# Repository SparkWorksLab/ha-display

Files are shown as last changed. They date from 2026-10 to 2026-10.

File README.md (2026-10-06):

<div align="center">

# Home Assistant Display






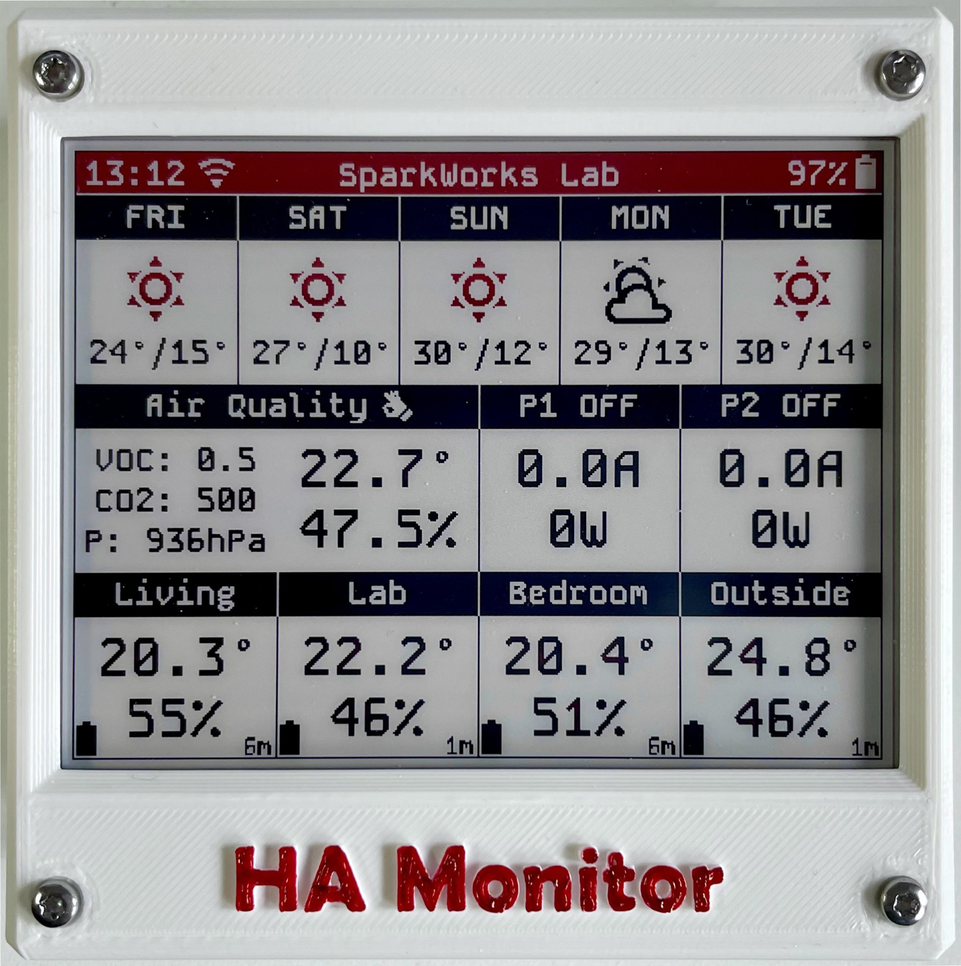
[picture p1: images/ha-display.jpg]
HA Display


**A low-power ESPHome e-paper dashboard for Home Assistant.**

A battery-powered Home Assistant display built around an ESP32-S3 and a 4.2" three-color e-paper display.

The device periodically wakes up, connects to Home Assistant, retrieves sensor data, updates the display, and then returns to deep sleep to minimize power consumption.

</div>

---

## Contents

- [Overview](#overview)
- [Features](#features)
- [System Architecture](#system-architecture)
- [Project Structure](#project-structure)
- [Display](#display)
- [Power Management](#power-management)
- [Home Assistant Integration](#home-assistant-integration)
- [Hardware](#hardware)
- [Firmware](#firmware)
- [Enclosure](#enclosure)
- [Installation](#installation)
- [Future Improvements](#future-improvements)
- [Design Principles](#design-principles)
- [References](#references)
- [License](#license)

---

## Overview

The **Home Assistant Display** is a battery-powered e-paper dashboard
designed to provide a quick overview of home information without requiring
a permanently powered screen.

The display combines data from Home Assistant with measurements from local
sensors and presents the information through a modular set of e-paper
widgets.

The low-power architecture allows the device to remain in deep sleep for
most of the time, waking periodically to update the display.

The project is designed to be modular and expandable, with separate
documentation for the firmware, hardware, and enclosure.

---

## Features

* 4.2" three-color e-paper display.
* Home Assistant integration through the ESPHome API.
* Weather forecast display.
* Local temperature, humidity, and atmospheric pressure monitoring.
* BME688 gas resistance and air quality monitoring.
* Smart Plug status monitoring.
* Current and power consumption display.
* Room temperature and humidity monitoring.
* Sensor availability detection.
* Low-power operation using deep sleep.
  * Automatic configurable interval refresh cycle during the day.
  * Extended deep sleep during the night.
* Manual wake-up button.  
* Li-Ion battery voltage monitoring.
* Wi-Fi connection status indication.
* Home Assistant API connection status indication.
* Configurable RGB debug LED.
* Modular display and widget architecture.
* Doxygen documentation.
* *Fail-Safe Operation:* Network mitigation routines preventing infinite loops and battery drain during Wi-Fi or HA outages.

---

## System Architecture

```mermaid
flowchart LR

    HA[Home Assistant]

    subgraph Display["HA Display"]
        ESP[ESP32-S3]
        DISPLAY[4.2-inch E-paper Display]
        BME[BME688]
        BAT[Li-Ion Battery]
        BUTTON[Wake-up Button]
    end

    SENSORS[Room Sensors]
    PLUGS[Smart Plugs]
    WEATHER[Weather Integration]

    SENSORS --> HA
    PLUGS --> HA
    WEATHER --> HA

    HA <-->|ESPHome API / Wi-Fi| ESP

    BME -->|I2C| ESP
    BAT -->|GPIO1| ESP
    BUTTON -->|GPIO4| ESP
    ESP --> DISPLAY
```

The display acts as a low-power endpoint for Home Assistant.

Home Assistant provides aggregated data and configuration, while the ESP32
is responsible for local sensor measurements, display rendering,
connectivity, and power management.

---

## Project Structure

```text
.
├── enclosure/       # 3D-printable enclosure and mechanical documentation
├── firmware/        # ESPHome configuration and C++ firmware
├── hardware/        # Schematics, PCB layouts, and BOMs
├── images/          # Project images and documentation assets
├── README.md        # Main project documentation
└── LICENSE          # AGPL-3.0 License
```

Each major part of the project has its own documentation:

* [Firmware](firmware/) — ESPHome configuration, C++ code,
sensors, display widgets, power management, and Home Assistant
integration.
* [Hardware](hardware/) — electronics, schematics, PCB
revisions, and BOM.
* [Enclosure](enclosure/) — 3D-printable enclosure files,
assembly information, and mechanical details.

---

## Display

The display is divided into several independent widgets.

* **Header**

  * Last update time.
  * Wi-Fi and Home Assistant connection status.
  * Title.
  * Battery status.

* **Top Section**

  * Weather forecast.

* **Middle Section**

  * BME688 environmental and air quality data.
  * Smart Plug monitoring.

* **Bottom Section**

  * Room temperature and humidity sensors.

The display drawing code is organized into reusable functions. This makes it easy to modify the layout or add new widgets without turning the main ESPHome display lambda into a large block of code.

### Display Layout

The 400 × 300 px screen is divided into four sections, each mapped to positions and sizes defined in `layout.h`.

<div align="center">
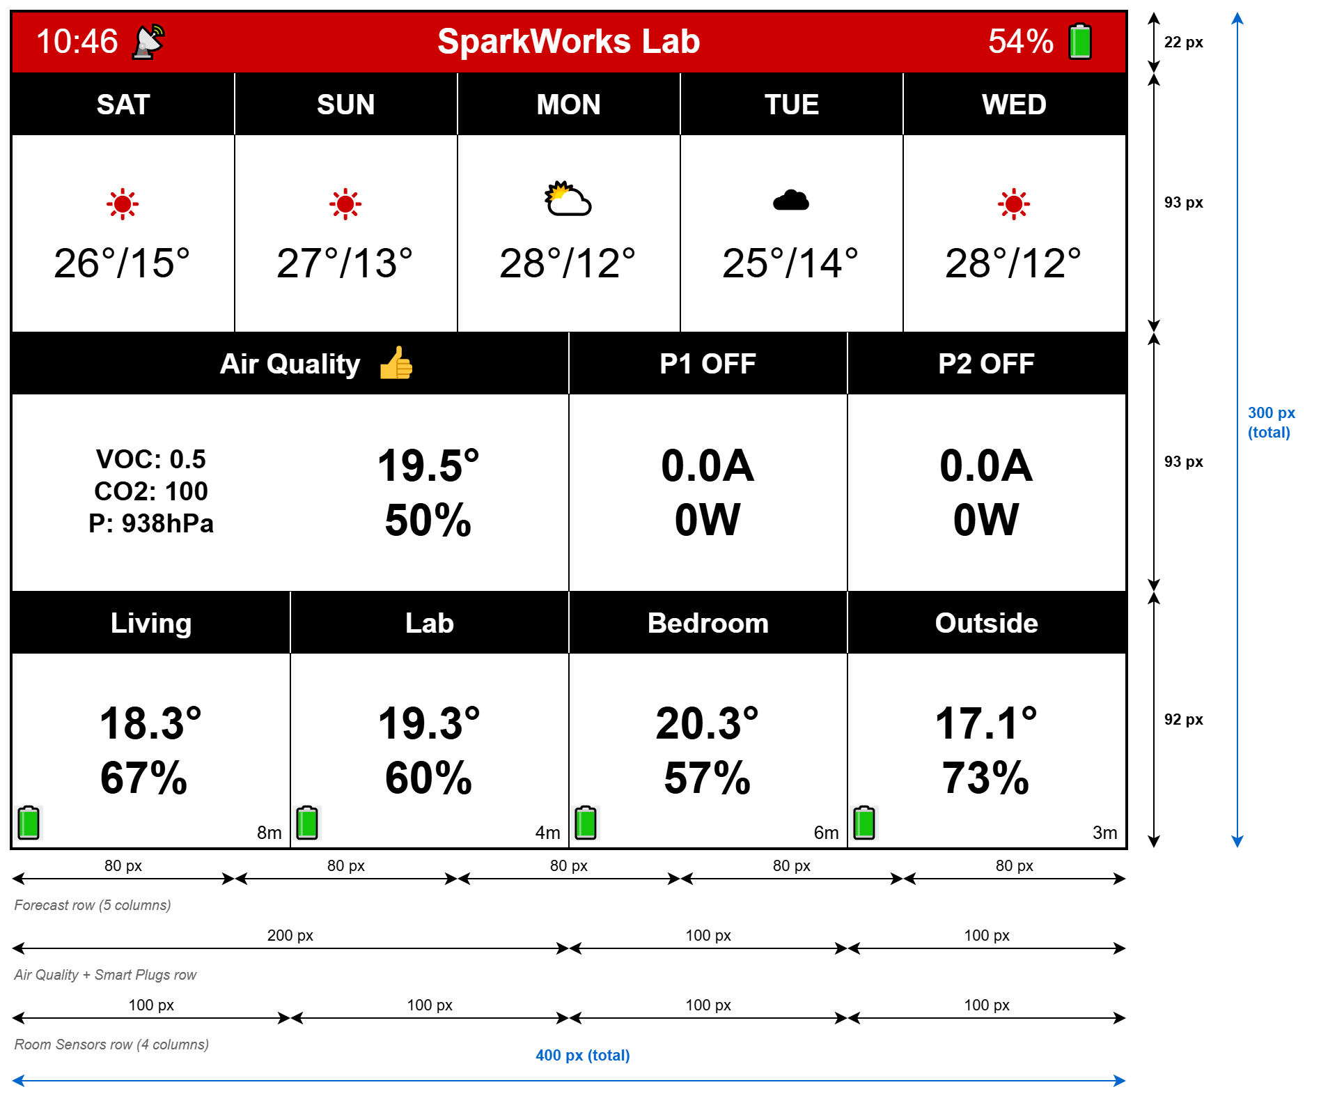
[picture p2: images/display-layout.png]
Display Layout

</div>

---

## Power Management

Low power consumption is one of the main goals of the project.

The device does not remain continuously connected to Wi-Fi. Instead, the ESP32 follows this cycle:

```mermaid
flowchart TD

    A[Wake up] --> B[Connect to Wi-Fi]

    B --> C[Connect to Home Assistant]

    C --> D[Receive Home Assistant data]

    D --> E[Read local sensors]

    E --> F[Update e-paper display]

    F --> G[Wait for display refresh]

    G --> L{Deep sleep enabled?}

    L -->|On| H{Night period?}

    H -->|No| I[Deep sleep for configured interval]

    H -->|Yes| J[Calculate time until wake time]

    J --> K[Extended deep sleep]

    I --> A
    K --> A

    L -->|Off| M[Wait configured interval]
    M --> D

    BUTTON[Manual wake-up button] -. GPIO4 .-> A
```

During the day, the display wakes up and refreshes at the interval configured through Home Assistant.

During the night, it enters a longer deep sleep period and automatically wakes up at the configured morning wake time.

The sleep schedule and daytime sleep duration can be configured directly
from Home Assistant without recompiling or reflashing the firmware.

A physical wake-up button can also be used to wake the device manually.

For detailed implementation information, see
[Power Management](firmware/README.md#power-management) in the firmware
documentation.

---

## Home Assistant Integration

The display communicates with Home Assistant through the ESPHome API.

Home Assistant provides:

* Room sensor data.
* Smart Plug information.
* Weather forecast data.
* Sleep schedule configuration.
* Daytime sleep duration.
* Deep-sleep enable/disable state.

Several Home Assistant helpers are used as persistent configuration
parameters for the display.

The current configuration includes:

* Sleep start hour.
* Wake-up hour.
* Daytime sleep duration.
* Deep-sleep enable/disable.

Because these values are stored by Home Assistant, they remain available while the ESP32 is in deep sleep.

When the display wakes and reconnects to Home Assistant, it retrieves the current configuration and uses it to determine its next operating cycle.

Changes made in Home Assistant therefore take effect on the next wake-up cycle.

The physical wake-up button can be used to apply configuration changes immediately instead of waiting for the next scheduled wake-up.

Detailed Home Assistant configuration is documented in the
[firmware](firmware/README.md#home-assistant-integration) documentation.

---

## Hardware

The HA Display has been developed through two hardware versions:

### Prototype

The prototype is built using an **ESP32-S3-DevKitC-1 development board** and a
2.54mm pitch protoboard. It was used to develop and validate the hardware and
software before designing the dedicated PCB.

Main hardware components:

* ESP32-S3-DevKitC-1 development board.
* WeAct Studio 4.2" (400 × 300 px) three-color e-paper display.
* Bosch BME688 environmental and air quality sensor.
* Li-Ion 18650 battery.
* 1S BMS/protection module.
* TPS63802 buck-boost 3,3v converter module.
* TP4056 USB-C Li-Ion charger module.
* 1 x push button for manual wake-up.

[View prototype hardware documentation](hardware/prototype/README.md)

### v1.0 Dedicated PCB

<div align="center">
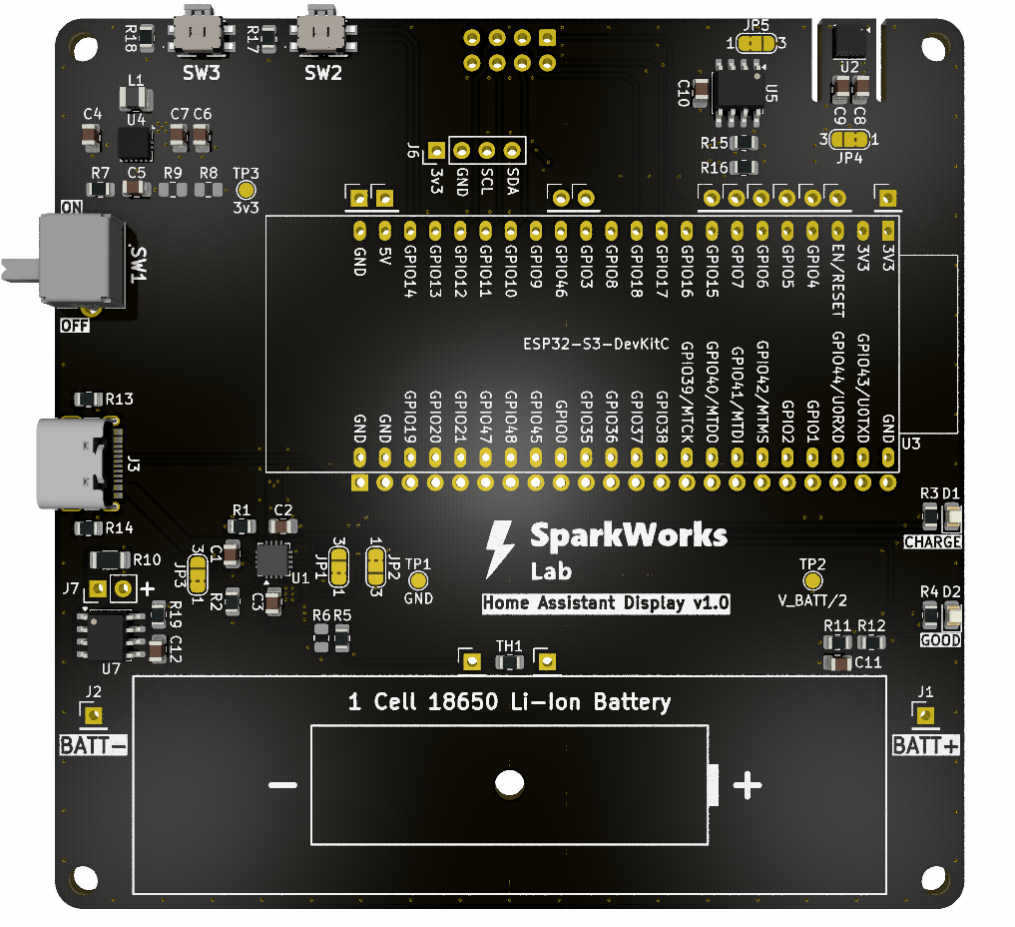
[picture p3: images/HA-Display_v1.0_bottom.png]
Wiring

</div>

The v1.0 hardware replaces the prototype wiring with a **dedicated 4-layer PCB** designed specifically for the HA Display with controlled USB differential pair impedances and optimized power and ground planes.
* ESP32-S3-DevKitC-1 development board.
* WeAct Studio 4.2" (400 × 300 px) three-color e-paper display.
* Bosch BME680/BME688 environmental sensor.
* Li-Ion 18650 battery.
* BQ24072: Li-Ion battery charger and power-path management IC (prioritizes USB input, bypassing cell micro-cycling).
* TPS63001: High-efficiency buck-boost converter ensuring a stable 3.3V rail down to battery cutoff.
* XB8089D: Integrated SOP8 advanced battery protection sub-circuit.
* Redundant DPDT Switch: Dual parallel-trace slide switch ensuring high mechanical robustness and reduced contact resistance.
* EEPROM: Onboard I2C storage for non-volatile data storage.
* 2 x push buttons for navigation and manual wake-up.
* Test points for debugging and measurements.
* Expansion headers for additional peripherals.
* Jumper at GND to measure current consumption easily.

[View v1.0 hardware documentation](hardware/v1.0/README.md)

### Home Assistant Server

Both versions communicate with a **Home Assistant server running on a
Raspberry Pi 3 B+** through ESPHome.

---

## Firmware

The firmware is based on ESPHome with an additional modular C++ layer for display widgets, battery estimation, power management, layout, and other reusable functionality.

The firmware configuration is divided into small YAML packages, while application-specific functionality is implemented through C++ header files.

This separation makes the firmware easier to maintain and allows hardware configuration, Home Assistant entities, display layout, and application logic to evolve independently.

Go to [firmware](firmware/README.md) documentation.

---

## Enclosure

The project includes a dedicated 3D-printed enclosure designed around the
display and electronics.

The enclosure documentation contains:

* STL files.
* Assembly information.
* Mechanical details.
* Printing recommendations.

Go to [enclosure](enclosure/README.md) documentation.

---

## Installation

The complete installation procedure is documented in the
[firmware](firmware/README.md#installation) documentation.

The general process is:

1. Install Python and ESPHome.
2. Clone this repository.
3. Configure the Home Assistant entities.
4. Configure Wi-Fi credentials.
5. Install the required Home Assistant package.
6. Configure the Home Assistant helpers.
7. Compile the ESPHome firmware.
8. Upload the firmware to the ESP32.

---

## Future Improvements

Some ideas for future development include:

* Particulate matter monitoring.
* Dedicated CO₂ measurement.
* Additional air quality sensors.
* Improved BME688 gas analysis and classification.
* ADC calibration based on measured voltage.
* Battery discharge testing and a custom State of Charge curve.
* Improved State of Charge estimation.
* Dynamic e-paper refresh timing.
* Historical sensor trends.
* Additional Home Assistant entities.
* Configurable display layouts.

---

## Design Principles

The goal of this project is to create a simple, low-power, and fully customizable Home Assistant information display.

The project focuses on:

* Low power consumption.
* Modular code.
* Reusable display widgets.
* Easy integration with Home Assistant.
* Battery operation.
* Simple and accessible hardware.
* Easy future expansion.

The architecture intentionally separates Home Assistant data aggregation from the ESP32 application logic.

Home Assistant provides the information and configuration, while the ESP32 focuses on local sensing, display rendering, connectivity, and power management.

---

## References

* [Home Ambient (Faulty Project).](https://faultyproject.es/category/proyectos/home-ambient/)
* [ESPHome E-ink Weather board.](https://github.com/xangin/eink-weather-board)
* [Material Design Icons Library.](https://pictogrammers.com/library/mdi/)

---

## License

The source code in this repository is licensed under the GNU Affero General Public License v3.0 (AGPL-3.0).

See the [LICENSE](LICENSE) file for the full license text.

Third-party assets included in this repository may be distributed under their respective licenses.

### Third-Party Assets

This project includes the Material Design Icons webfont by Pictogrammers.

The font is distributed under the Apache License 2.0.

See the [Pictogrammers](https://pictogrammers.com/) website and the [Apache License 2.0](https://www.apache.org/licenses/LICENSE-2.0) for more information.

### Images and Photographs

Unless otherwise stated, photographs and images in this repository are copyright © 2026 SparkWorksLab.

They are provided for documentation and demonstration purposes only and are not covered by the AGPL-3.0 License.

Permission is required for their reuse, redistribution, or commercial use.

---

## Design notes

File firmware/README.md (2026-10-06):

<div align="center">

# HA Display: Firmware

ESPHome firmware, configuration, and C++ application logic
for the Home Assistant Display

</div>

---

## Contents

- [Overview](#overview)
- [Project Structure](#project-structure)
- [Firmware Architecture](#firmware-architecture)
- [ESPHome Configuration](#esphome-configuration)
- [C++ Application Layer](#c-application-layer)
- [Display System](#display-system)
- [Home Assistant Integration](#home-assistant-integration)
- [Monitoring and Sensors](#monitoring-and-sensors)
- [Power Management](#power-management)
- [Deep Sleep Configuration](#deep-sleep-configuration)
- [Manual Wake-Up](#manual-wake-up)
- [Connectivity and Fail-Safe Operation](#connectivity-and-fail-safe-operation)
- [Debug RGB LED](#debug-rgb-led)
- [BSEC2 Experimental Configuration](#bsec2-experimental-configuration)
- [Installation](#installation)
- [Configuration](#configuration)
- [Troubleshooting](#troubleshooting)
- [Doxygen Documentation](#doxygen-documentation)

---

## Overview

The firmware is based on **ESPHome** and uses a modular C++ application layer for functionality that is more convenient to implement outside the ESPHome YAML configuration.

ESPHome provides:

* Hardware configuration.
* Wi-Fi connectivity.
* Home Assistant API communication.
* Sensor integration.
* Deep-sleep control.
* GPIO handling.
* OTA and serial firmware updates.

The C++ layer provides:

* Display rendering.
* Reusable display widgets.
* Display layout definitions.
* Battery State of Charge estimation.
* Power-management calculations.
* Weather icon conversion.
* RGB debug LED helpers.

The firmware is intentionally divided into small reusable components so that individual parts can be modified without turning the main ESPHome configuration into a large monolithic file.

---

## Project Structure

The project is divided into small, reusable YAML configuration files and C++ header files.

```text
.
├── fonts/
│   └── materialdesigniconswebfont.ttf
│
├── include/
│   ├── battery.h
│   ├── display.h
│   ├── display_bsec.h
│   ├── layout.h
│   ├── led.h
│   ├── power.h
│   └── weather_icons.h
│
├── packages/
│   ├── display.yaml
│   ├── entities.yaml
│   ├── fonts.yaml
│   ├── forecast.yaml
│   ├── sensors.yaml
│   ├── sensors_bsec.yaml
│   └── wifi.yaml
│
├── .gitignore
├── HA-Display.yaml
├── ha_display_sensor.yaml
├── README.md
└── secrets.example.yaml
```
---

## Firmware Architecture

The main ESPHome configuration includes the individual YAML packages and the C++ header files.

The standard firmware uses `sensors.yaml` and `display.h`.

An alternative BSEC2 configuration is provided in `sensors_bsec.yaml` and `display_bsec.h` for experimental or continuously powered applications.

Only one sensor/display profile is intended to be active at a time.

The default profile uses `sensors.yaml` and `display.h`, while the optional BSEC2 profile uses `sensors_bsec.yaml` and `display_bsec.h`.

---

## ESPHome Configuration

The firmware configuration is split into several ESPHome packages, each responsible for a specific subsystem.

### `HA-Display.yaml`

This is the main ESPHome configuration file.

It defines the ESP32-S3 hardware, includes the project packages, references the external C++ headers, and provides the top-level configuration required to build the firmware.

The main configuration should remain relatively small because most functionality is delegated to the individual packages and C++ modules.

### `display.yaml`

Configures the e-paper display and the main display update lambda.

The display layout is implemented through reusable drawing functions defined in the project header files.

### `entities.yaml`

Defines the Home Assistant entities imported into ESPHome, including room sensors, Smart Plug data, battery information, and configurable sleep schedule parameters.

### `fonts.yaml`

Defines the fonts and Material Design icon glyphs used by the e-paper display.

### `forecast.yaml`

Defines the Home Assistant entities used to retrieve weather forecast data and makes the forecast attributes available to the display.

### `sensors.yaml`

Same configuration as `sensors.yaml` adding BSEC2 algorithm for the BME68x sensor.

### `sensors_bsec.yaml`

Configures locally connected sensors and Home Assistant entities used by the display.

Includes environmental measurements, battery monitoring, and configurable  sleep schedule entities.

### `wifi.yaml`

Configures the Wi-Fi connection and ESPHome API used to communicate with Home Assistant.

### `secrets.example.yaml`

Copy this file to `secrets.yaml` and update it with your own Wi-Fi credentials:

```yaml
wifi_ssid: "YOUR_WIFI_SSID"
wifi_password: "YOUR_WIFI_PASSWORD"
```

The `secrets.yaml` file should not be committed to the repository.

---

## C++ Application Layer

Application-specific functionality is implemented through C++ header files.

### `battery.h`

Contains battery-related helper functions.

The battery State of Charge is estimated using a voltage lookup table instead of a simple linear calculation.

This provides a more realistic approximation of the charge level of a Li-Ion cell.

### `display.h`

Provides reusable functions for drawing the different widgets displayed on the e-paper dashboard.

 The widgets include the header, weather forecast, environmental sensor, Smart Plug display, room sensors, and battery indicators. For example:

* `drawHeader()`.
* `drawBatteryIcon()`.
* `drawForecast()`.
* `drawAirSensor()`.
* `drawSmartPlugs()`.
* `drawRoomSensors()`.

### `display_bsec.h`

Same as `display.h` replacing `drawAirSensor()` to show BSEC2 calculated data.

### `layout.h`

Contains display layout definitions such as:

* Screen dimensions.
* Widget positions.
* Margins.
* Alignment constants.
* Widget spacing.

Keeping the layout separate from the drawing functions makes it easier to reorganize the display without modifying the widget implementation.

### `led.h`

Contains helper functions for the RGB status LED.

The LED can be enabled for debugging purposes using a compile-time definition:

```cpp
#define DEBUG_LED
```

When debugging is disabled, the LED control code is excluded from the build.

### `power.h`

Contains power management helper functions.

The current implementation calculates the deep sleep duration dynamically based on the current time and configurable sleep start and wake times.

This allows the display to:

* Refresh every 15 minutes during the day.
* Enter a single extended deep sleep period during the night.
* Wake up automatically at the configured morning wake time.

### `weather_icons.h`

Provides helper functions and definitions for converting Home Assistant weather condition strings into the corresponding Material Design icons used by the e-paper display.

### `.gitignore`

The repository includes a `.gitignore` file to prevent personal configuration files, such as `secrets.yaml`, from being committed.

---

## Home Assistant Integration

The display communicates with Home Assistant through the ESPHome API.

Several Home Assistant entities are imported directly into ESPHome, including room temperature and humidity sensors, smart plug states and power consumption data, weather forecast information, and the sleep schedule configuration.

### Home Assistant Helpers

The sleep schedule is configured using three Home Assistant `input_number` helpers:

* `input_number.sleep_start_hour`
* `input_number.wake_hour`
* `input_number.sleep_duration`

Create these helpers from:

**Settings → Devices & services → Helpers → Create Helper → Number**

Configure them with:

<div align="center">

| Helper | Minimum | Maximum | Step |
| --- | --- | --- | --- |
| `input_number.sleep_start_hour` | 0 | 23 | 1 |
| `input_number.wake_hour` | 0 | 23 | 1 |
| `input_number.sleep_duration` | 5 | 60 | 5 |

</div>

These helpers act as the persistent configuration for the display. ESPHome reads their values after connecting to Home Assistant following a wake-up. See [Deep Sleep Configuration](#deep-sleep-configuration) for how they are used.

An additional helper controls whether the display uses deep sleep at all:

* `input_boolean.ha_display_deep_sleep`

Create it from:

**Settings → Devices & services → Helpers → Create Helper → Toggle**

No further configuration is needed — the display reads its state directly. See [Deep Sleep Configuration](#deep-sleep-configuration) for how it's used.

### Home Assistant Package

Some of the data displayed by the display is prepared by Home Assistant.

Before installing the ESPHome configuration, copy:

```text
ha_display_sensor.yaml
```

to the Home Assistant packages directory:

```text
/config/packages/
```

Make sure that the packages directory is included in your Home Assistant configuration.

For example:

```yaml
homeassistant:
  packages: !include_dir_named packages
```

Then restart Home Assistant.

The package creates the template entities required by the display, including weather forecast data and sensor availability states.

### Weather Forecast

Home Assistant is responsible for retrieving and preparing the weather forecast.

A template sensor stores the forecast data as attributes. The ESPHome device retrieves these attributes and displays them on the e-paper screen.

The forecast includes:

* Day.
* Weather condition.
* Maximum temperature.
* Minimum temperature.

The forecast data can be refreshed periodically to prevent outdated information from being displayed.

This is configured in the `ha_display_sensor.yaml` file.

```yaml
- trigger:
    - platform: homeassistant
      event: start

    - platform: time_pattern
      hours: "/1"
      minutes: 1

  action:
    - service: homeassistant.update_entity
      target:
        entity_id: weather.forecast_home

    - delay: "00:00:02"
    
    - service: weather.get_forecasts
      target:
        entity_id: weather.forecast_home
      data:
        type: daily
      response_variable: daily

  sensor:
    - name: "eink_sensors"
      unique_id: eink_sensors

      state: >
        {{ daily['weather.forecast_home'].forecast[0].condition }}

      attributes:

        forecast_day_1: >
          {{ as_timestamp(daily['weather.forecast_home'].forecast[0].datetime)
             | timestamp_custom('%a')
             | upper }}

        forecast_condition_1: >
          {{ daily['weather.forecast_home'].forecast[0].condition }}

        forecast_temp_max_1: >
          {{ daily['weather.forecast_home'].forecast[0].temperature | round }}

        forecast_temp_min_1: >
          {{ daily['weather.forecast_home'].forecast[0].templow | round }}
```

---

## Monitoring and Sensors

The display combines data received from Home Assistant with locally connected sensors.

### Room Temperature and Humidity Sensors

The display retrieves temperature and humidity data from Home Assistant entities. This allows the device to display environmental data collected by external sensors distributed throughout the home.

The sensor entities can be easily adapted in `entities.yaml` to match the Home Assistant configuration.

```yaml
sensor:
  - platform: homeassistant
    id: t1_temperature
    entity_id: sensor.t1_temperature

  - platform: homeassistant
    id: t1_humidity
    entity_id: sensor.t1_humidity

  - platform: homeassistant
    id: t1_battery
    entity_id: sensor.t1_battery 

  - platform: homeassistant
    id: t1_age
    entity_id: sensor.t1_sensor_age    
```

Sensor availability is also monitored to detect stale or unavailable devices. When a sensor has not reported data for an extended period, its status can be visually indicated on the display instead of presenting outdated measurements as current values.

A binary sensor is created in `entities.yaml` to handle this functionality.

```yaml
binary_sensor:
  - platform: homeassistant
    entity_id: binary_sensor.t1_sensor_state
    id: t1_online
```    

Stale or unavailable sensors can therefore be visually highlighted instead of displaying outdated values as if they were current. This is configured in the `ha_display_sensor.yaml` file. 

```yaml
- trigger:
    - platform: time_pattern
      minutes: "/1"

  binary_sensor:
    - name: T1 Sensor State
      unique_id: t1_online
      state: >
        {{ (now() - states.sensor.t1_temperature.last_updated).total_seconds() < 900 }}
```

Each Room Sensor widget displays:

* Sensor name.
* Temperature.
* Humidity.
* Battery Level.
* Minutes since last update.
* Status (Red color if not updated for more than 15 minutes).

The widget implementation is reusable:

```cpp
drawRoomSensor(
    it,
    x,
    y,
    name,
    temperature,
    humidity,
    battery,
    status,
    age);
```

A higher-level function handles the collection of Room Sensors widgets:

```cpp
drawRoomSensors(it);
```

### Smart Plug Monitoring

The display currently displays the status of two Home Assistant Smart Plugs.

The sensor entities can be easily adapted in `entities.yaml` to match the Home Assistant configuration.

```yaml
sensor:
  - platform: homeassistant
    id: p1_voltage
    entity_id: sensor.p1_voltage
  - platform: homeassistant
    id: p1_current
    entity_id: sensor.p1_current  
  - platform: homeassistant
    id: p1_power
    entity_id: sensor.p1_power

switch:
  - platform: homeassistant
    entity_id: switch.p1
    id: p1_state    
```

Each Smart Plug widget displays:

* Plug name.
* ON/OFF state.
* Current consumption.
* Power consumption.

The widget implementation is reusable:

```cpp
drawSmartPlug(
    it,
    x,
    y,
    name,
    state,
    current,
    power);
```

A higher-level function handles the collection of Smart Plug widgets:

```cpp
drawSmartPlugs(it);
```

Additional Smart Plugs can therefore be added without modifying the individual widget implementation.

### Environmental Sensor

A Bosch BME680/BME688 environmental sensor is connected directly to the ESP32 through the I2C bus.

The standard firmware uses the conventional BME68x sensor driver rather than BSEC2. This configuration provides the basic environmental measurements while remaining fully compatible with the low-power deep-sleep architecture.

The sensor is connected through I2C using address `0x77`. The address depends on the CS pin configuration of the sensor module: with CS pulled high, the sensor uses `0x77`; with CS pulled low, it uses `0x76`.

The standard configuration provides measurements such as:

* Temperature.
* Relative humidity.
* Atmospheric pressure.
* Gas resistance.
* IAQ.

The sensor values are available both:

* On the e-paper display.
* As entities in Home Assistant.

The project also includes an optional BSEC2-based configuration. See [BSEC2 Experimental Configuration](#bsec2-experimental-configuration) for details.

The environmental values are provided directly by the BME688, while the air-quality indicators are calculated by BSEC2 from the sensor measurements.

The temperature, humidity and pressure values use small change filters to avoid unnecessary updates when the measured value changes only slightly.

The IAQ value is classified into seven levels according to the BSEC IAQ scale and represented directly on the e-paper display using the corresponding Material Design Icon:

<div align="center">

<table>
<tr>
<td align="center">
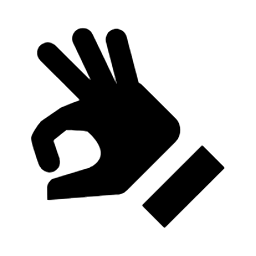
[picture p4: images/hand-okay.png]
<br>
<code>mdi-hand-okay</code><br>
<sub>Excellent · IAQ 0–50</sub>
</td>

<td align="center">
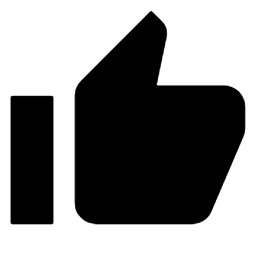
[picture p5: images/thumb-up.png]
<br>
<code>mdi-thumb-up</code><br>
<sub>Good · IAQ 51–100</sub>
</td>

<td align="center">
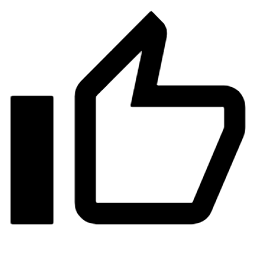
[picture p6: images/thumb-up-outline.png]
<br>
<code>mdi-thumb-up-outline</code><br>
<sub>Lightly polluted · IAQ 101–150</sub>
</td>

<td align="center">
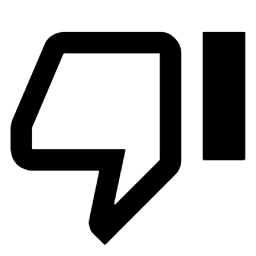
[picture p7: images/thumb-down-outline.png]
<br>
<code>mdi-air-thumb-down-outline</code><br>
<sub>Moderately polluted · IAQ 151–200</sub>
</td>

<td align="center">
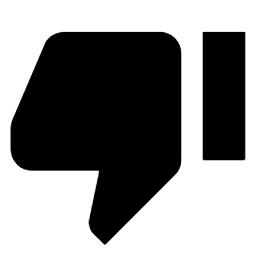
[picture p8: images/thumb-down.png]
<br>
<code>mdi-thumb-down</code><br>
<sub>Heavily polluted · IAQ 201–250</sub>
</td>

<td align="center">
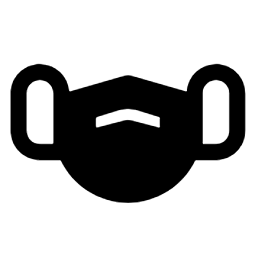
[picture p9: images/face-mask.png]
<br>
<code>mdi-face-mask</code><br>
<sub>Severely polluted · IAQ 251–350</sub>
</td>

<td align="center">
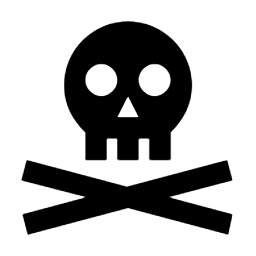
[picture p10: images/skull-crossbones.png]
<br>
<code>mdi-skull-crossbones</code><br>
<sub>Extremely polluted · IAQ 351+</sub>
</td>
</tr>
</table>

</div>

The BME688 widget displays:

* Temperature and relative humidity.
* Atmospheric pressure.
* Gas resistance.
* IAQ classification and its corresponding icon.

The sensor values are available both:

* On the e-paper display.
* As entities in Home Assistant.

### Battery Monitoring

The device is powered by a single Li-Ion 18650 cell.

Battery voltage is measured through a 470 kΩ + 470 kΩ resistive divider feeding an ESP32 ADC pin (GPIO1), scaled back up in software via the `multiply: 2.068` filter in `sensors.yaml`. The high resistance value keeps the divider's constant current draw negligible.

Multiple ADC samples can be averaged to reduce measurement noise. Currently 64 samples are averaged.

The measured voltage is converted into an estimated State of Charge using a voltage lookup table.

Example voltage points:

```text
4.20 V → 100%
4.00 V → 80%
3.95 V → 70%
3.60 V → 50%
3.30 V → 20%
3.00 V → 0%
```

Linear interpolation is used between the lookup table points.

This provides a more realistic battery percentage estimate than a simple linear conversion between minimum and maximum voltage.

---

## Power Management

Low power consumption is one of the main goals of the project.

The device does not remain continuously connected to Wi-Fi. Instead, the ESP32 follows this cycle:

```mermaid
flowchart TD

    A[Wake up] --> B[Connect to Wi-Fi]

    B --> C[Connect to Home Assistant]

    C --> D[Receive Home Assistant data]

    D --> E[Read local sensors]

    E --> F[Update e-paper display]

    F --> G[Wait for display refresh]

    G --> L{Deep sleep enabled?}

    L -->|On| H{Night period?}

    H -->|No| I[Deep sleep for configured interval]

    H -->|Yes| J[Calculate time until wake time]

    J --> K[Extended deep sleep]

    I --> A
    K --> A

    L -->|Off| M[Wait configured interval]
    M --> D

    BUTTON[Manual wake-up button] -. GPIO4 .-> A
```

The firmware distinguishes between daytime and nighttime operation.

During the daytime, the display periodically wakes and refreshes.

During the configured nighttime period, the firmware calculates the time until the next configured wake hour and enters an extended deep-sleep period.

This avoids unnecessary Wi-Fi connections and display refreshes while the display is not expected to be used.

---

## Deep Sleep Configuration

The sleep behavior can be configured directly from Home Assistant without recompiling or reflashing the firmware.

The following Home Assistant helpers are used:

<div align="center">

| Helper | Purpose |
| --- | --- |
| `input_number.sleep_start_hour` | Start of the nighttime sleep period |
| `input_number.wake_hour` | Morning wake-up time |
| `input_number.sleep_duration` | Daytime deep-sleep duration |
| `input_boolean.ha_display_deep_sleep` | Enables or disables deep sleep |

</div>

### Sleep Start and Wake Time

The sleep and wake hours can be adjusted between 0 and 23 in one-hour
increments using the dedicated Home Assistant helpers:

<div align="center">

Sleep schedule configuration

</div>

These values are stored by Home Assistant and remain available while the
ESP32 is sleeping.

When the device wakes and reconnects to Home Assistant, ESPHome retrieves the current values and uses them to calculate the next sleep period.

The deep sleep duration is calculated dynamically based on the current time and the configured sleep schedule.

This significantly reduces unnecessary Wi-Fi connections and battery consumption during the night.

### Daytime Sleep Duration

The daytime deep-sleep duration is also configurable through a dedicated Home Assistant helper:

<div align="center">

Daytime sleep duration

</div>

This allows the normal daytime refresh interval to be changed without modifying the firmware.

For example:

```text
5 minutes  → more frequent updates
15 minutes → default configuration
30 minutes → lower power consumption
60 minutes → maximum battery-oriented operation
```
The actual allowed range and step size are defined by the Home Assistant
helper configuration.

### Continuous Operation Mode

Deep sleep can be temporarily disabled from Home Assistant using the dedicated helper:

<div align="center">

Deep sleep toggle

</div>

When deep sleep is enabled, the display follows its normal cycle:

<div align="center">

**Wake → Update → Sleep**

</div>

When deep sleep is disabled, the device skips the deep-sleep transition and instead remains running, refreshing the display periodically through the configured interval defined to perform display update according to the helper `input_number.sleep_duration` value:

```yaml
# Timer to update screen when Deep Sleep is OFF.
interval:
  - interval: 1min
    then:
      - if:
          condition:
            binary_sensor.is_off: ha_display_deep_sleep
          then:
            # Increase counter.
            - lambda: |-
                id(display_update_counter)++;

            - if:
                condition:
                  # Check counter and sleep duration.
                  lambda: |-
                    const float sleep_duration = id(ha_sleep_duration).state;
                    return !isnan(sleep_duration) &&
                           sleep_duration > 0 &&
                           id(display_update_counter) >= (int) sleep_duration;
                then:
                  # Update screen if the configured interval has elapsed.
                  - lambda: |-
                      id(display_update_counter) = 0;
                  - script.execute: refresh_display
```                  

If the Home Assistant value is not yet available, for example during startup or when the ESP32 cannot connect to Home Assistant, the value may be reported as `NaN`. The firmware explicitly checks for this condition and skips the refresh until a valid value is received.

This mode is useful during:

* Development.
* Debugging.
* Hardware testing.
* Long-term sensor operation.
* BSEC2 experimentation.
* OTA Firmware Update.

When deep sleep is disabled, the display shows the corresponding sleep-off indicator in the header:

<div align="center">

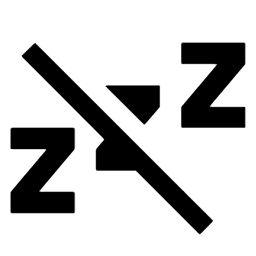
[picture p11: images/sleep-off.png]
<br>
<code>mdi-sleep-off</code><br>
<sub>Deep Sleep disabled</sub>

</div>

---

## Manual Wake-Up

A physical push button can also be used to wake the display manually while it is in deep sleep.

The button is connected to GPIO4 and configured as an ESP32 EXT1 wake-up source:

```yaml
deep_sleep:
  id: deep_sleep_control
  run_duration: 75s
  sleep_duration: 15min

  esp32_ext1_wakeup:
    pins:
      - number: GPIO4
    mode: ANY_HIGH
```

The GPIO is normally held LOW using a hardware pull-down resistor. Pressing the button drives the pin HIGH, waking the ESP32 from deep sleep.

This allows the display to be refreshed on demand and configuration changes in Home Assistant to be applied immediately, without waiting for the next scheduled wake-up cycle.

---

## Connectivity and Fail-Safe Operation

The firmware is designed to avoid excessive battery drain when the network
or Home Assistant is unavailable.

### Wi-Fi Connection

The device waits for a limited period while connecting to Wi-Fi.

If the connection cannot be established, the boot sequence continues instead of remaining indefinitely in a connection loop.

### Home Assistant API

After Wi-Fi has connected, the firmware waits for the Home Assistant API connection for a limited period.

If Home Assistant is unavailable, the device continues its operating cycle instead of remaining connected indefinitely.

This is particularly important for a battery-powered device because an uncontrolled retry loop could prevent the ESP32 from entering deep sleep.

### Status Indication

The display can show the current status using Material Design icons:

<div align="center">

<table>
<tr>
<td align="center">
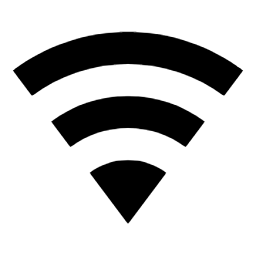
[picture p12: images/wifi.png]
<br>
<code>mdi-wifi</code><br>
<sub>Wi-Fi + HA connected</sub>
</td>

<td align="center">
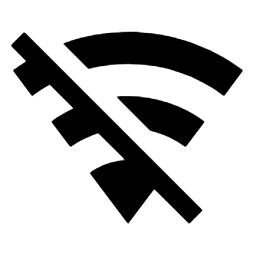
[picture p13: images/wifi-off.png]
<br>
<code>mdi-wifi-off</code><br>
<sub>Wi-Fi disconnected</sub>
</td>

<td align="center">
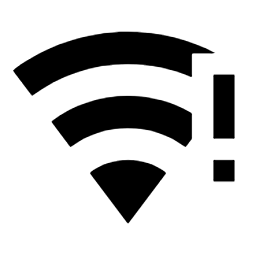
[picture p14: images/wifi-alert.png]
<br>
<code>mdi-wifi-alert</code><br>
<sub>HA unavailable</sub>
</td>

<td align="center">
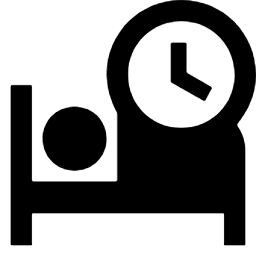
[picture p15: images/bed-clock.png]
<br>
<code>mdi-bed-clock</code><br>
<sub>Sleep period</sub>
</td>
</tr>
</table>

</div>

This information is useful when troubleshooting connection problems or when the device wakes up without being able to contact Home Assistant.

---

## Debug RGB LED

An RGB LED is used during development to provide visual feedback about the current device state.

Examples include:

* Wi-Fi connected.
* Wi-Fi disconnected.
* Home Assistant API connected.
* Display refresh in progress.

The LED can be disabled for normal operation.

The debug functionality is controlled at compile time:

```cpp
#ifdef DEBUG_LED

// Debug LED code.

#endif
```

This makes it possible to keep the debugging functionality in the source code without enabling the LED during normal operation.

---

## BSEC2 Experimental Configuration

An alternative BSEC2 configuration is provided in `packages/sensors_bsec.yaml`.

BSEC2 can provide additional calculated air-quality indicators from the BME688 measurements, including:

* Breath VOC Equivalent (bVOCe).
* CO₂ Equivalent (eCO₂).
* Indoor Air Quality (IAQ).
* IAQ accuracy.
* IAQ classification.

A typical BSEC2 configuration uses parameters such as:

```yaml
bme68x_bsec2_i2c:
  i2c_id: i2c_a
  address: 0x77
  model: bme688
  operating_age: 28d
  sample_rate: ULP
  supply_voltage: 3.3V
  state_save_interval: 6h
```

The BSEC2 configuration includes:

* BME688 model selection.
* I2C address 0x77.
* Ultra Low Power (ULP) sample rate.
* 3.3 V supply voltage.
* 28-day operating age.
* Periodic BSEC2 state storage.

To enable this configuration comment/uncomment these lines in the `HA-Display.yaml` file before compiling:

```yaml
esphome:
  includes:
    - include/display.h                         # Comment this line to use BSEC2.
    #- include/display_bsec.h                   # Uncomment this line to use BSEC2.
  
packages:
  sensor: !include packages/sensors.yaml        # Comment this line to use BSEC2.
  #sensor: !include packages/sensors_bsec.yaml  # Uncomment this line to use BSEC2.
```

### Deep-Sleep Compatibility

BSEC2 maintains an internal environmental model that depends on continuous time progression on the host MCU.

The monitor's low-power architecture relies heavily on ESP32 deep sleep, which interrupts this continuous execution.

Testing showed that after entering deep sleep and waking again, the BSEC2 algorithm returns to a Stabilizing state and does not provide the expected
continuous calibration behavior.

For this reason, the BSEC2 configuration is **optional and experimental** and is not used by the standard low-power firmware.

Keeping the BSEC2 implementation in a separate configuration allows it to remain available for:

* Future experimentation.
* Continuously powered variants.
* Dedicated air-quality nodes.
* Applications where deep sleep is not required.

The standard monitor therefore uses the conventional BME688 configuration instead.

---
## Installation

1. Install [Python 3.12](https://www.python.org/downloads/) or later.

   > **Windows users:** during installation, check **"Add python.exe to PATH"** in the installer. Without it, `python`/`pip` won't be recognized directly in the terminal — you'd need to always call them through the `py` launcher (`py -m pip`, `py -m esphome`, etc.), which is what these instructions use to stay safe either way.

2. Install ESPHome via pip:

```bash
   py -m pip install esphome
```

   This project was built and tested with **Python 3.12.10** and **ESPHome 2026.6.5**.

3. Install [Visual Studio Code](https://code.visualstudio.com/) if you want to use the recommended development environment.
4. Clone this repository and open the folder in VSCode.
5. Copy `ha_display_sensor.yaml` to the Home Assistant `packages` directory.
6. Make sure the packages directory is included in `configuration.yaml`.
7. Restart Home Assistant.
8. Create the `input_number.sleep_start_hour`, `input_number.wake_hour`, and `input_number.sleep_duration` helpers in Home Assistant.
9. Configure their minimum, maximum, and step values as described above.
10. Copy `secrets.example.yaml` to `secrets.yaml`.
11. Update the Wi-Fi credentials.
12. Update the Home Assistant entity IDs to match your installation.
13. Configure the GPIO pins according to your hardware.
14. Compile and upload the firmware from the VSCode integrated terminal:

```bash
    py -m esphome compile firmware/HA-Display.yaml
    py -m esphome upload firmware/HA-Display.yaml --device COMxx
```

Replace `COMxx` with the serial port your board enumerates as (check **Device Manager** on Windows). The first upload always requires this USB connection.

The main configuration can reference the Wi-Fi credentials using:

```yaml
ssid: !secret wifi_ssid
password: !secret wifi_password
```
---

## Configuration

Several parts of the project are hardware-specific and may need to be adapted to your setup.

### Display

Configure the SPI and control pins according to your display wiring.

### Home Assistant Entities

Update the entity IDs for:

* Sleep schedule helpers.
* Room temperature sensors.
* Room humidity sensors.
* Smart Plugs.
* Weather entity.

### Battery

The battery lookup table can be adjusted for different battery cells or based on a measured discharge curve.

### Deep Sleep

The daytime refresh interval and nighttime sleep schedule can be modified to achieve the desired balance between:

* Battery life.
* Data freshness.

---

## Troubleshooting

### Wi-Fi icon shows disconnected (`mdi-wifi-off`)

* Double-check `wifi_ssid` and `wifi_password` in `secrets.yaml`.
* Make sure the device is within range of the access point; the ESP32-S3 only waits 20 seconds for a connection before continuing the boot sequence.
* Check the router for 2.4 GHz availability — the ESP32-S3 Wi-Fi radio does not support 5 GHz networks.

### Wi-Fi connected but Home Assistant icon shows alert (`mdi-wifi-alert`)

* Confirm the device has been added as an integration in **Settings → Devices & services → ESPHome**.
* The device only waits 15 seconds for the API connection after Wi-Fi succeeds; on a slow network this may not be enough — consider increasing the `wait_until` timeout in `HA-Display.yaml`.
* Check that port 6053 (ESPHome API) is not blocked by a firewall between the device and the Home Assistant host.

### A sensor widget always shows `N/A` or `--`

* Verify the `entity_id` in `entities.yaml` matches the exact entity ID in Home Assistant (**Developer Tools → States**).
* An entity that is `unavailable` or `unknown` in Home Assistant will also read as an invalid state on the display.

### A Room Sensor is shown in red even though it just reported data

* Make sure the staleness check uses `last_updated`, not `last_changed` — the latter only updates when the *value* changes, so a sensor reporting the same reading repeatedly (a stable temperature, for example) would be incorrectly flagged as offline even while reporting normally.
* The default staleness threshold is 15 minutes (900 seconds), defined in `ha_display_sensor.yaml`. Adjust the `< 900` value if your sensors report less frequently.

### Weather forecast never updates

* Confirm `ha_display_sensor.yaml` was copied into `/config/packages/` and that Home Assistant was restarted afterward.
* Check that `weather.forecast_home` matches your actual weather entity ID — if it differs, update it in `ha_display_sensor.yaml`.
* The forecast only refreshes on boot and once per hour (`minutes: 1`); wait for the next cycle or trigger `homeassistant.update_entity` manually from **Developer Tools → Actions**.

### Battery percentage seems inaccurate

* The ADC reads raw voltage on GPIO1 through a resistor divider; the `multiply: 2.068` filter in `sensors.yaml` compensates for the current divider I've measured. If you built the voltage divider with different resistor values, recalculate and update this factor.
* Battery SoC uses a lookup table (`battery.h`) modeled for a generic Li-Ion 18650 discharge curve — it will drift from the real charge level of a different cell chemistry or a heavily aged battery.

### Device wakes up every 15 minutes even during the configured night period

* Confirm the `input_number.sleep_start_hour` and `input_number.wake_hour` helpers exist and are reachable — `getSleepDuration()` falls back to the normal 15-minute cycle whenever Home Assistant time (`id(ha_time)`) is not valid, which happens if the API connection failed during that wake cycle.
* Sleep hour values equal to each other (`sleep_start_hour == wake_hour`) are treated as invalid and also fall back to the 15-minute cycle.

### Display does not refresh

* Ensure `update_interval: never` is kept in `display.yaml` — refreshes are triggered manually via `component.update: eink` in the `refresh_display` script, not on a timer.

### Display shows ghosting

* Check your display model refresh time and adjust the `refresh_display` script delay to ensure full refresh is done.

### Device never enters deep sleep / battery drains fast

* The `refresh_display` script waits up to ~26 seconds (2 s + 22 s + 2 s) before calling `deep_sleep.enter`, on top of up to 35 seconds for Wi-Fi/HA connection during boot. If your `run_duration` (currently 75 s) is close to this total, a slow network round-trip can push the device to hit `run_duration` and force-sleep before completing a clean shutdown. Consider increasing `run_duration` slightly if this happens often.

---

## Doxygen Documentation

The project uses Doxygen-style comments to document reusable functions.

Example:

```cpp
/**
 * @brief Draws a Smart Plug widget.
 *
 * Displays the plug name, ON/OFF state, current and power consumption.
 *
 * @param it Display instance.
 * @param x Horizontal coordinate measured from the top-left corner of the widget.
 * @param y Vertical coordinate measured from the top-left corner of the widget.
 * @param name Smart Plug name.
 * @param state Current ON/OFF state.
 * @param current Current consumption in amperes.
 * @param power Power consumption in watts.
 */
```

The goal is to keep the code understandable and maintainable as additional widgets and sensors are added.

---

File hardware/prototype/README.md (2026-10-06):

<div align="center">

# HA Display Prototype Hardware

The prototype version is based on an ESP32-S3 development board running ESPHome with the ESP-IDF framework.

</div>

---

## Contents

- [Bill of Materials](#bill-of-materials)
- [Pin Assignment](#pin-assignment)
- [Wiring Diagram](#wiring-diagram)
- [Prototype Assembly](#prototype-assembly)

---

## Bill of Materials

* 1 x ESP32-S3-DevKitC-1 development board as main microcontroller.
* 1 x WeAct Studio 4.2" (400 × 300 px) three-color e-paper display.
* 1 x Bosch BME688 environmental and air quality sensor module.
* 1 x Li-Ion 18650 battery.
* 1 x Li-Ion 18650 battery holder.
* 1 x 1S battery protection circuit module.
* 1 x TP4056 USB-C Li-Ion charger module.
* 1 x TPS63802 buck-boost 3,3v converter module.
* 2 x Resistor 100KΩ-1MΩ for voltage divider to sense battery voltage. Currently used 261KΩ.
* 1 x Momentary push button for manual wake-up.
* 1 x Resistor 10KΩ for wake-up button pull down.
* 1 x SPDT or DPDT switch (minimum rated 200mA).
* 1 x Protoboard with 2.54mm spacing. Optimal dimensions: 92 x 90mm.
* 4 x Hex pillars male-female M2.5 x 5mm height.
* 4 x Hex pillars male-female M2.5 x 10mm height.
* 4 x M2.5 x 10mm screws.
* Wrapping wire for signal connections.
* Normal wire (AWG 24-28) for power connections.
* Female pinheads: 2 x 24 + 1 x 6. *Optional but highly recommended*.
* 60mm of double sided tape to stick the battery holder to the PCB.

---

## Pin Assignment

<div align="center">

| ESP32-S3 GPIO | Function |
|---|---|
| GPIO1 | Battery voltage measurement |
| GPIO8 | I²C SDA |
| GPIO9 | I²C SCL |
| GPIO10 | LCD CS |
| GPIO11 | LCD SDI (MOSI) |
| GPIO12 | LCD SCK |
| GPIO4 | Button 1 |
| GPIO16 | LCD RST |
| GPIO17 | LCD D/C |
| GPIO18 | LCD BUSY |
| GPIO48 | DEBUG LED |

</div>

---

## Wiring diagram

<div align="center">

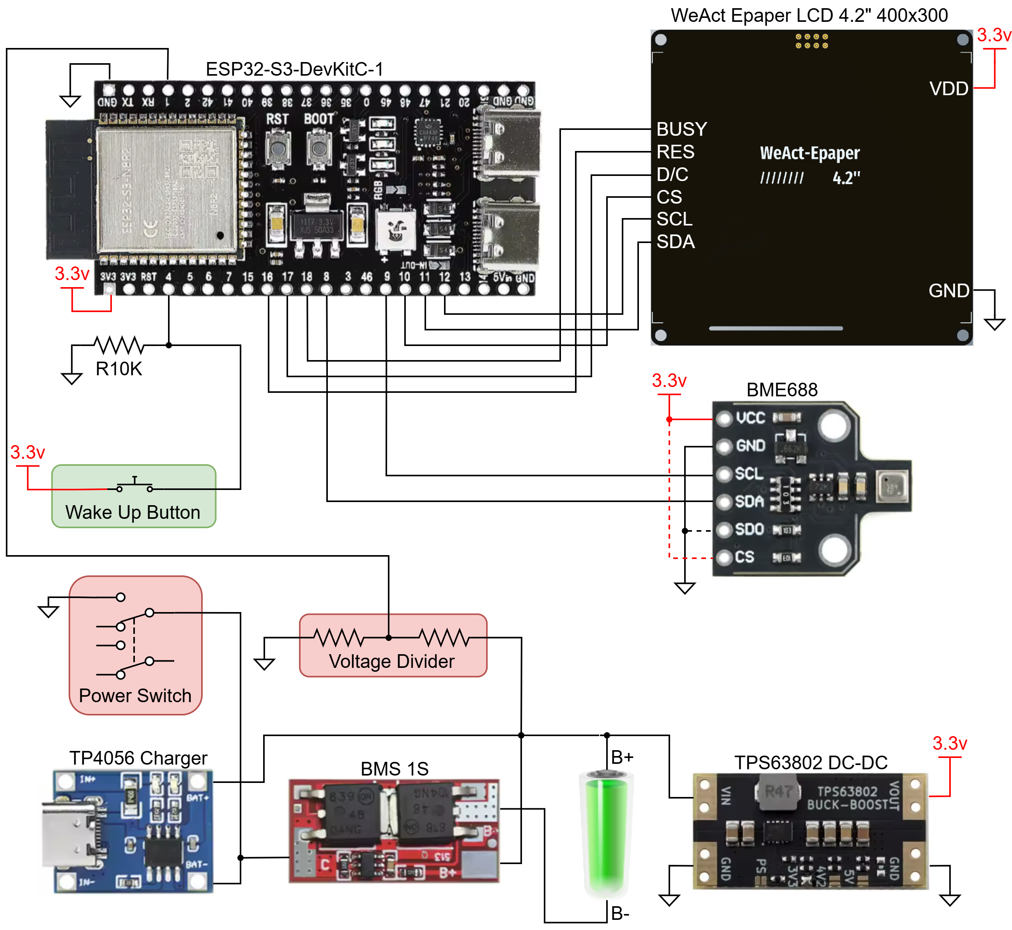
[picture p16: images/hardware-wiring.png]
Wiring


</div>

---

## Prototype Assembly

The prototype is built on a **2.54mm pitch protoboard** using a combination of wrapping wire and conventional wire connections.

* **Wrapping wire** is used for signal connections between the ESP32-S3 and the different peripherals. This keeps the signal wiring compact and makes it easier to route the relatively large number of connections required by the prototype.
* **AWG 28 wire** is used for power connections.
* The **2.54mm protoboard** provides the mechanical and electrical base for the prototype and allows the different modules to be mounted and interconnected without requiring a dedicated PCB during the prototyping stage.

This approach was chosen to allow the hardware and software to be developed and tested quickly before moving to a dedicated PCB design.

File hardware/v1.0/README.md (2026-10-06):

<div align="center">

# HA Display: Hardware v1.0

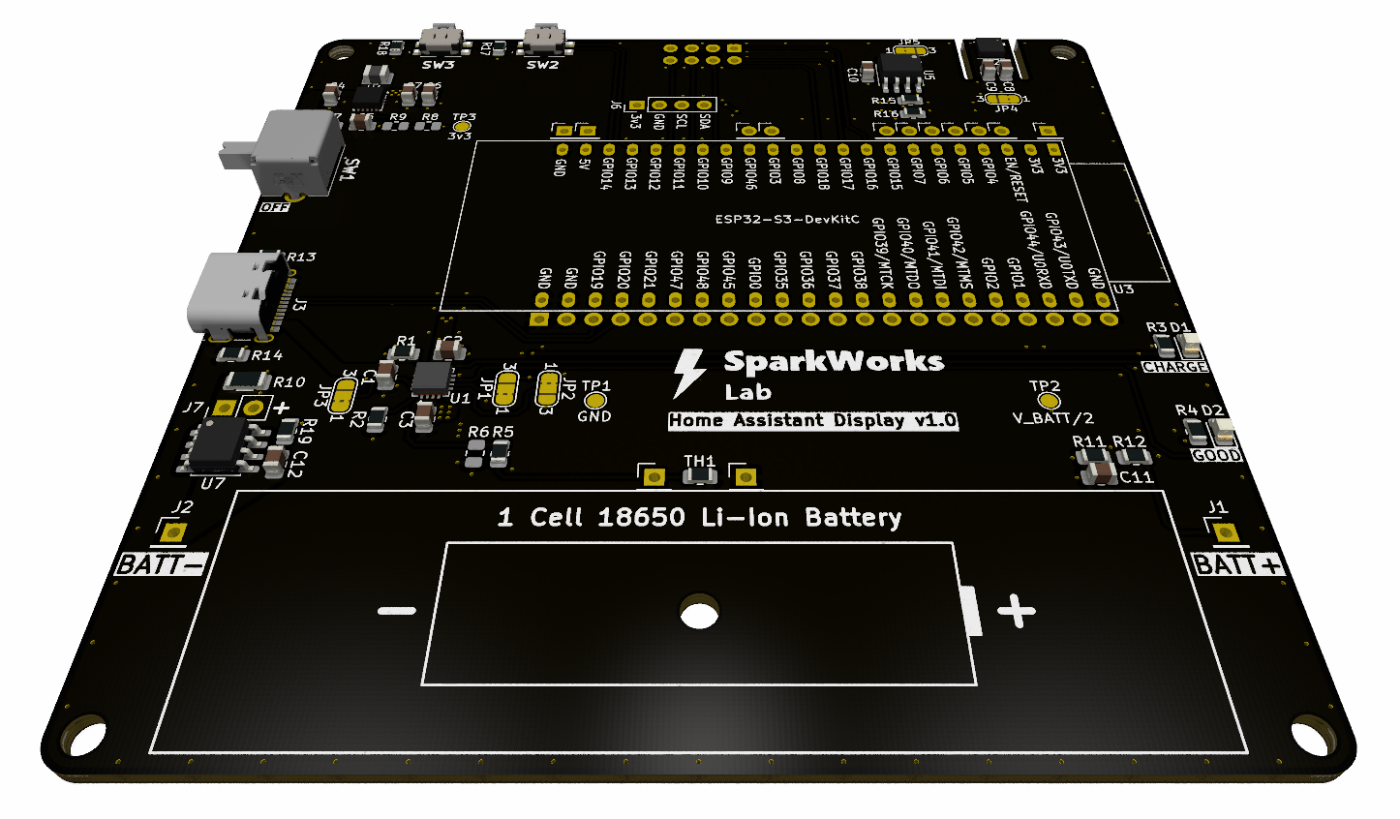
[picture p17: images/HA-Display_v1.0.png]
HA Display v1.0 PCB


The v1.0 hardware is the first dedicated PCB design for the HA Display,
replacing the prototype assembled on a 2.54mm pitch protoboard.

</div>

---

- [Overview](#overview)
- [Main Features](#main-features)
- [Hardware Specifications](#hardware-specifications)
- [Power Management](#power-management)
- [Pin Assignment](#pin-assignment)
- [PCB Configuration](#pcb-configuration)
- [Schematic](#schematic)
- [PCB Design](#pcb-design)
- [Bill of Materials](#bill-of-materials)
- [Manufacturing Files](#manufacturing-files)
- [Hardware Assembly](#hardware-assembly)
- [Version History](#version-history)

---

## Overview

The dedicated PCB integrates the main hardware required by the HA Display
into a single board, reducing wiring and simplifying assembly.

The board is designed around the ESP32-S3-DevKitC-1 and provides connections
for the e-paper display, BME688 sensor, battery, charger, wake-up button
and other peripherals.

### Top Side

<div align="center">

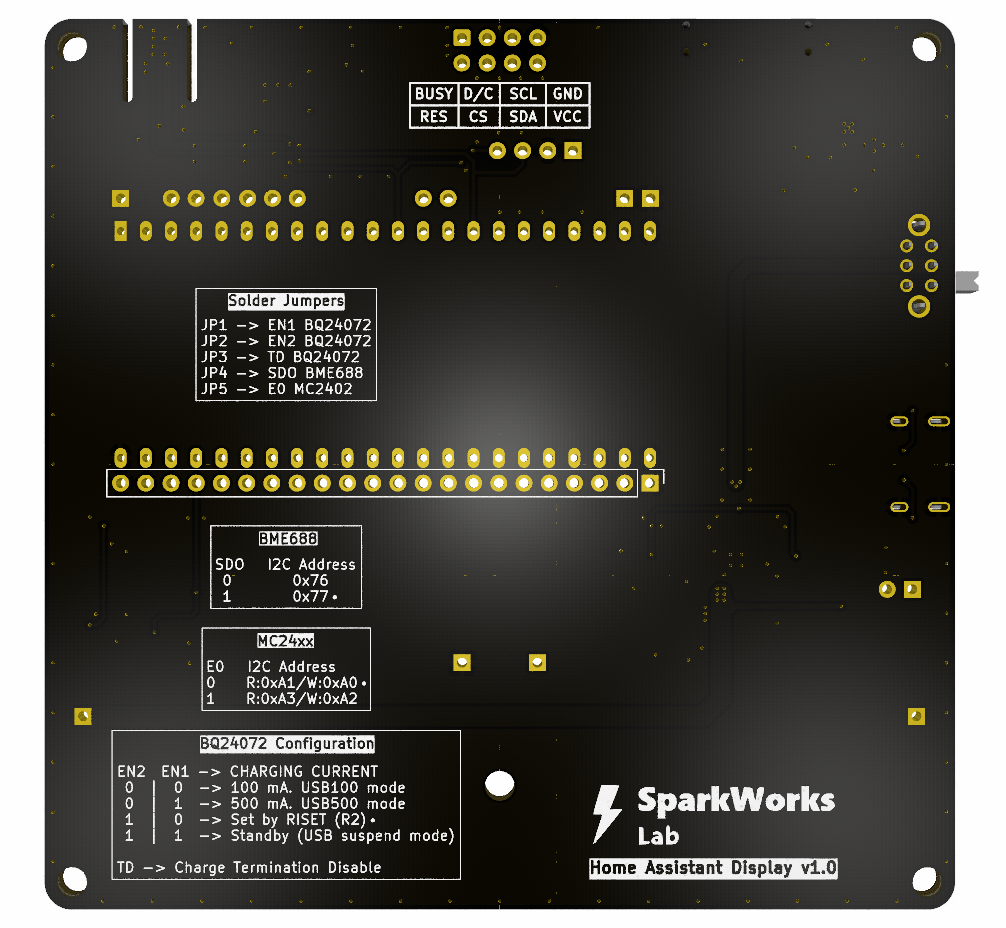
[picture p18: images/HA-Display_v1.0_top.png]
HA Display v1.0 PCB


</div>

### Bottom Side

<div align="center">

HA Display v1.0 PCB

</div>

---

## Main Features

* ESP32-S3-DevKitC-1 as main microcontroller.
* Dedicated connection for the 4.2" e-paper display.
* BME688 environmental and air quality sensor interface.
* 1-cell 18650 Li-Ion battery connection.
* Integrated battery voltage measurement.
* BQ24072-based USB-C battery charging and monitoring.
* TPS63001 DC-DC converter to supply 3.3v to the board.
* XB8089D Battery protection IC.
* 2 user buttons capable of wake-up the ESP32.
* Power switch.
* Charging status LEDs.
* EEPROM memory for persistent data storage.
* USB Type-C connector for power and ESP32 USB connectivity.
* Test points for debugging and measurements.
* Expansion headers for additional peripherals.
* Removable GND jumper for easy insertion of an ammeter when measuring
  board current consumption.

---

## Hardware Specifications

<div align="center">

| Parameter | Specification |
|---|---|
| Main MCU | ESP32-S3-DevKitC-1 |
| Display | WeAct Studio 4.2" 400 × 300 px, 3-color e-paper |
| Environmental sensor | Bosch BME688 |
| Battery | 1S 18650 Li-Ion |
| Charger | BQ24072 USB-C |
| Battery protection | XB8089D |
| DC-DC converter | TPS63001 buck-boost |
| EEPROM | M24C64 |
| PCB revision | v1.0 |
| PCB stackup | 4-layer |

</div>

---

## Power Management

The board includes a dedicated power-management chain consisting of:

- **BQ24072** — Li-Ion charging and power-path management.
- **XB8089D** — battery protection.
- **TPS63001** — buck-boost conversion to 3.3 V.
- **Battery voltage divider** — provides battery-voltage monitoring to the ESP32-S3.

---

## Pin Assignment

<div align="center">

| ESP32-S3 GPIO | Function |
|---|---|
| GPIO1 | Battery voltage measurement |
| GPIO8 | I²C SDA |
| GPIO9 | I²C SCL |
| GPIO10 | LCD CS |
| GPIO11 | LCD SDI (MOSI) |
| GPIO12 | LCD SCK |
| GPIO13 | Button 1 |
| GPIO14 | Button 2 |
| GPIO16 | LCD BUSY |
| GPIO17 | LCD RST |
| GPIO18 | LCD D/C |
| GPIO19 | USB D− |
| GPIO20 | USB D+ |
| GPIO48 | DEBUG LED |

</div>

---

## PCB Configuration

This PCB has been designed taking into consideration maximum flexibility.

### Battery Charging Current

Battery charging current can be adjusted with JP1 and JP2 jumpers.

<div align="center">

|JP2 | JP1 | CHARGING CURRENT |
|---|---|---|
| 0  |  0  | 100 mA. USB100 mode |
| 0  |  1  | 500 mA. USB500 mode |
| 1  |  0  | Set by R<sub>ISET<sub> |
| 1  |  1  | Standby (USB suspend mode) |

</div>

By default, R<sub>ISET</sub> is used to set charging current to 890mA: 

$$
R_{\text{ISET}} \, (R_2) = \frac{890 \text{ A}\Omega}{890 \text{ mA}} = 1 \text{ k}\Omega
$$

Current limit is set to 1.3A using R<sub>ILIM</sub>:

$$
R_{\text{ILIM}} \, (R_1) = \frac{1550 \text{ A}\Omega}{1.3 \text{ A}} = 1.2 \text{ k}\Omega
$$

### Charge Termination

The BQ24072 contain a TD input that allows termination to be enabled/ disabled. Connect TD to a logic high to disable charge termination. When termination is disabled, the device goes through the pre-charge, fast-charge and CV phases, then remains in the CV phase. During the CV phase, the charger maintains the output voltage at BAT equal to VBAT(REG), and charging current does not terminate.

This pin can be adjusted using JP3, by default is driven LOW to enable Charge Termination. If Charge Termination needs to be disabled, it can be driven HIGH easily.

### BME68x I²C Address

The BME68x I²C address can be selected using the `J4` solder jumper:

* `0x77` — default configuration.
* `0x76` — when `J4` is soldered to GND.

### MC24xx I²C Address

The MC24xx I²C address can be selected using the `J5` solder jumper:

* `R:0xA1/W:0xA0` — default configuration.
* `R:0xA3/W:0xA2` — when `J5` is soldered to 3.3v.

### Test Points

Three Test Points are provided in the Bottom Layer to enable debugging.

<div align="center">

| TP | Function |
|---|---|
| TP1 | Ground Connection |
| TP2 | Battery Voltage measurement (Vbatt/2) |
| TP3 | 3.3v Supply Voltage |

</div>

### Current Measurement

Current consumption can be measured removing R10 (0Ω) and using J7 to connect an ammeter to the groung return of the circuit. Note that `+` sign is marked on the PCB to ensure right polarity.

This can be very useful to estimate battery life according to the selected refresh interval.

---

## Schematic

The complete schematic is available in both PDF and KiCad formats.

[View the schematic](schematic/HA-Display_v1.0.pdf).

---

## PCB Design

The v1.0 hardware has been developed using a **dedicated 4-layer PCB** designed specifically for the HA Display with controlled USB differential pair impedances and optimized power and ground planes.

The PCB was designed using KiCad. The editable KiCad project files are provided in the `kicad/` directory.

---

## Bill of Materials

The complete Bill of Materials is available in:

* [BOM](manufacturing/HA-Display_v1.0_BOM.csv).

---

## Manufacturing Files

The Gerber and drill files required to manufacture the PCB are available in:

* [Gerber files](manufacturing/HA-Display_v1.0_Gerbers.zip).
* [BOM](manufacturing/HA-Display_v1.0_BOM.csv).
* [Centroid file](manufacturing/HA-Display_v1.0-all-pos.csv).

---

## Hardware Assembly

Refer to Hardware Assembly Guide in the [manufacturing](manufacturing/README.md) folder.

---

## Version History

<div align="center">

| Version | Description |
|---|---|
| v1.0 | First dedicated PCB design |

</div>

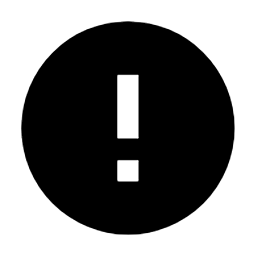
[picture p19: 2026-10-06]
images/alert-circle.png

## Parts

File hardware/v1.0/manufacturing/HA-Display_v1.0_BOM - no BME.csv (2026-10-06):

Comment | Designator | Footprint | LCSC Part Number
1uF | C1 | 805 | C28323
4.7uF | C2, C3 | 805 | C1779
10uF | C4, C6, C7 | 805 | C15850
0.1uF | C5, C8, C9, C10, C11, C12 | 805 | C49678
Red | D1 | 805 | C84256
Green | D2 | 805 | C2297
USB Type C | J3 | USB 16P | C3197684
2.2uH | L1 | 1008 | C576403
1K2 | R1 | 805 | C17379
1K | R2, R3, R4, R19 | 805 | C17513
0 | R5 | 805 | C17477
100 | R7 | 805 | C17408
0 | R10 | 1206 | C17888
470K | R11, R12 | 805 | C17709
5K1 | R13, R14, R17, R18 | 805 | C27834
2K2 | R15, R16 | 805 | C17520
DPDT | SW1 | DPDT SW | C221833
10K | TH1 | 805 | C73681
BQ24072RGTR | U1 | QFN-16-EP(3x3) | C140288
TPS63001DRCR | U4 | VSON-10-EP(3x3) | C28060
M24C64-RMN6TP | U5 | SOIC-8 | C79988
XB8089D | U7 | SOIC-8 EP | C79928

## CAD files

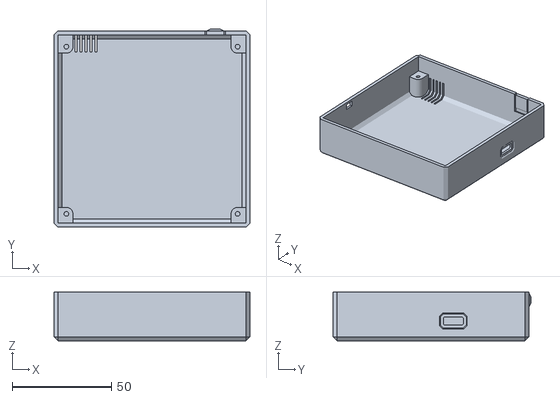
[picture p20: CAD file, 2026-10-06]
enclosure/HA-Display_Case_v1.0.stl
98.7 x 99.7 x 24.5

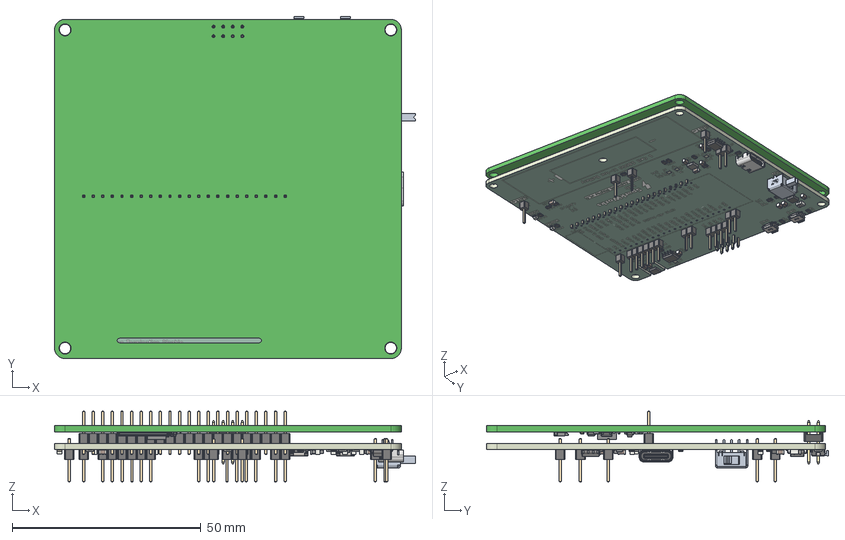
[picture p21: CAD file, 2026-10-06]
hardware/v1.0/3d/HA-Display_v1.0.step
95.5 x 90.6 x 18.8 mm
PinHeader_1x22_P254mm_Vertical
R0603 x 5
Extruded x 6
pin_header_awl254-dg-g08d
User Library-SOT23-3
Mid_Body x 9
Mark x 9
Leader x 3
FH34SRJ-24S-0.5SH_RGB4408131
SOD323 x 3
C_0805_2012Metric x 12
PinHeader_1x01_P254mm_Vertical x 15
R_0805_2012Metric x 19
R_1206_3216Metric
SOIC-8_3.9x4.9mm_P1.27mm x 2
L_1008_2520Metric
PinHeader_1x02_P254mm_Vertical
LED_0805_2012Metric x 2
Bosch_LGA_8_3x3mm_P08mm_ClockwisePinNumbering
frame x 2
pins x 2
pins_3 x 2
pins_1 x 2
pins_2 x 2
stem x 2
cover x 2
PinHeader_1x04_P254mm_Vertical
BODY-SON
OS-202011MA0QN1_SW0001_PRT
BODY-QFN
PIN1-ID
HA-CCAE_silkscreen x 2
HA-CCAE_soldermask x 2
HA-CCAE_PCB

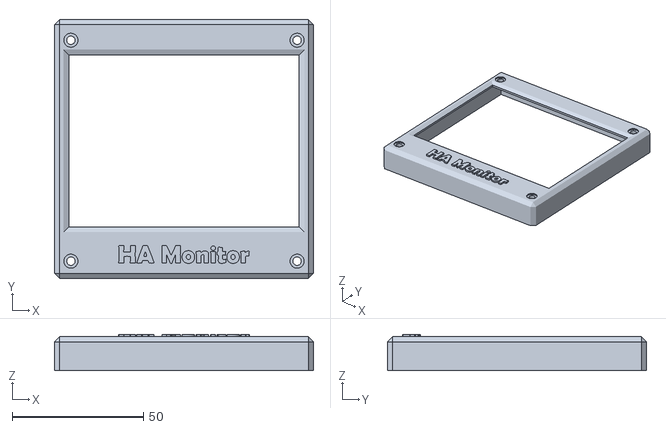
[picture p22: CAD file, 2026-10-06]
enclosure/HA-Display_Cover_v1.0.stl
98.7 x 98.7 x 13.8

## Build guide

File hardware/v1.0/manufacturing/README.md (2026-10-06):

<div align="center">

# HA Display: Hardware Assembly Guide

Wiring

*PCB manufacturing, assembly, and hardware preparation guide*

</div>

This guide provides instructions for manufacturing and assembling the Home Assistant Display hardware. It assumes basic knowledge of soldering and printed circuit board assembly.

The KiCad project files are included in the `kicad` folder and contain the complete schematic and PCB layout. No KiCad knowledge is required to order the PCB, but the files are provided for reference and for anyone who wants to modify or manufacture the board independently.

I use [JLCPCB](https://jlcpcb.com) for PCB manufacturing and assembly, but the same production files should be compatible with other PCB manufacturers.

---

## Contents

- [1. Generate the Gerber and Drill Files](#1-generate-the-gerber-and-drill-files)
- [2. Generate BOM and Centroid Files](#2-generate-bom-and-centroid-files)
- [3. Order the Assembled PCBs from JLCPCB](#3-order-the-assembled-pcbs-from-jlcpcb)
- [4. Order the Additional Parts](#4-order-the-additional-parts)
- [5. Finish the PCB](#5-finish-the-pcb)
- [6. Inspect and Test the Hardware](#6-inspect-and-test-the-hardware)
- [7. Flash the Firmware](#7-flash-the-firmware)

---

## 1. Generate the Gerber and Drill Files

The first step is to export the Gerber and Drill files from KiCad for PCB manufacturing. See the [JLCPCB Gerber and Drill File Generation guide](https://jlcpcb.com/help/article/16-How-to-generate-Gerber-and-Drill-files-in-KiCad-6) for detailed instructions.

Alternatively, you can use the ready-made
[JLCPCB Gerber Files](HA-Display_v1.0_Gerbers.rar) included with this project.
Keep the files compressed when uploading them to JLCPCB.

## 2. Generate BOM and Centroid Files

To use JLCPCB's SMT Assembly service, the BOM and Centroid files are also
required. [Follow these instructions provided by JLCPCB](https://jlcpcb.com/help/article/81-How-to-generate-the-BOM-and-Centroid-file-from-KiCAD). 

Alternatively, you can use the ready-made files included with this project:

* [JLCPCB BOM](HA-Display_v1.0_BOM.csv).
* [JLCPCB Centroid file](HA-Display_v1.0-all-pos.csv).

## 3. Order the Assembled PCBs from JLCPCB

1. Have the Gerber, Drill, BOM, and Centroid files handy. (Keep the files zipped)
2. Visit the [JLCPCB Website](https://www.jlcpcb.com).
3. Click the **Order Now** button in the top menu bar.
4. Click the **Add Gerber File** button.

<div align="center">
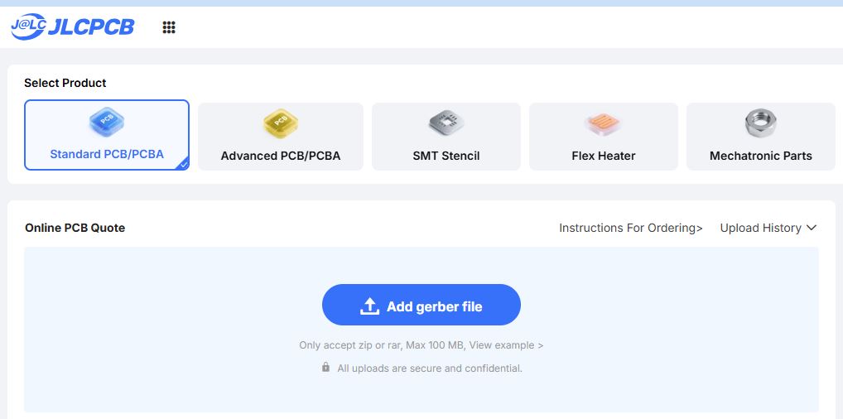
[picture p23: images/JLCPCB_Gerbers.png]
JLCPCB Gerbers Upload

</div>

5. Once [Gerber Files](HA-Display_v1.0_Gerbers.rar) are uploaded, you'll see the design in the viewer. You can adjust the PCB quantity you need in this step.

<div align="center">
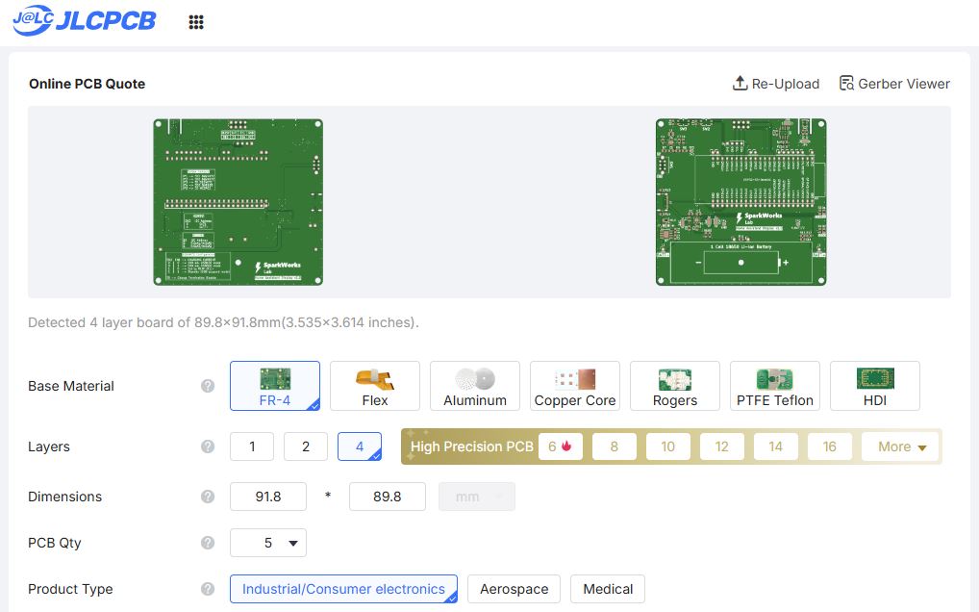
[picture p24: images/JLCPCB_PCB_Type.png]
JLCPCB Type

</div>

6. You can adjust **surface finish**. I personally prefer Black soldermask more than Green one, although you'll have to pay some extra money. Recommended to change the default HASL (with lead) to at least LeadFree HASL, as lead is toxic. If you want a better surface finish, select ENIG 1U".

<div align="center">
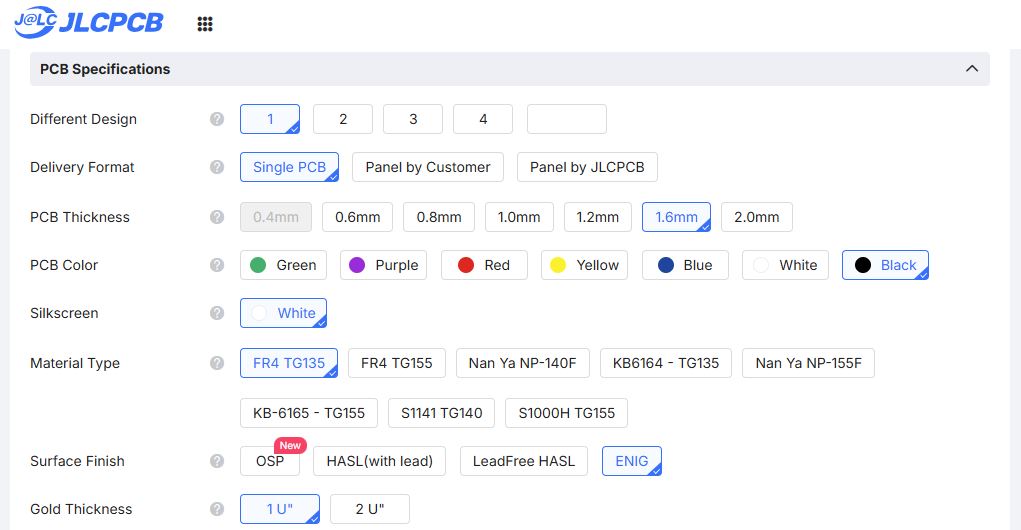
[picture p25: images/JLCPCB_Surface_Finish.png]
JLCPCB Surface Finish

</div>

7. In the High-spec section, it's recommended to activate **Confirm Production file**. 

<div align="center">
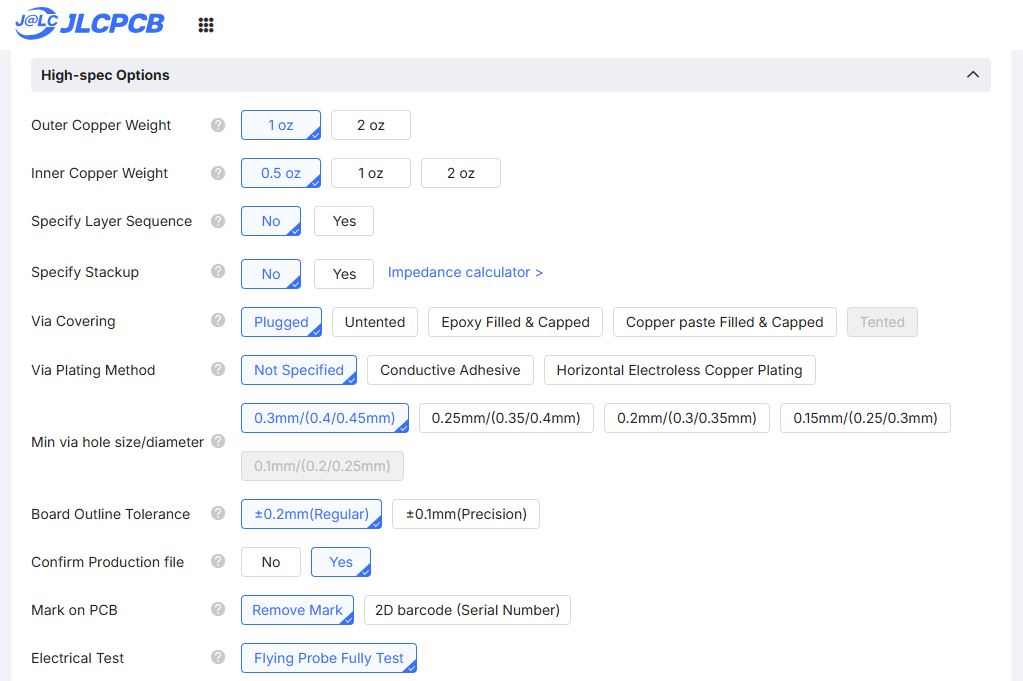
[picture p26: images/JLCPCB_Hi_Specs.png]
JLCPCB Hi specs

</div>

8. When **Confirm Production file** is activated, you'll be prompted whether to Confirm the file automatically after 48h. Mark the checkbox if you don't want your files to be confirmed automatically. Ensure you check your e-mail regularly to avoid any delays. 

<div align="center">
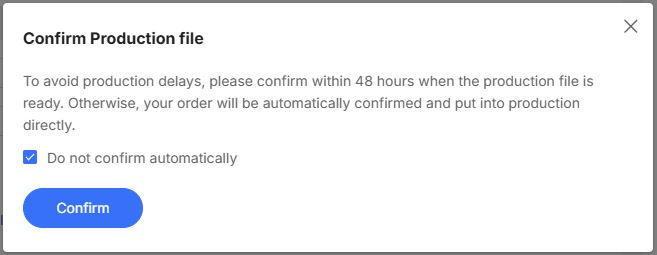
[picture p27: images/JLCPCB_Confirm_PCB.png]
JLCPCB Confirm PCB

</div>

9. Activate **PCB Assembly** section. Select the **Bottom side** to assemble the components. Adjust the quantity of Assembled PCB's you need. It's recommended to activate **Confirm Parts placement**. 

<div align="center">
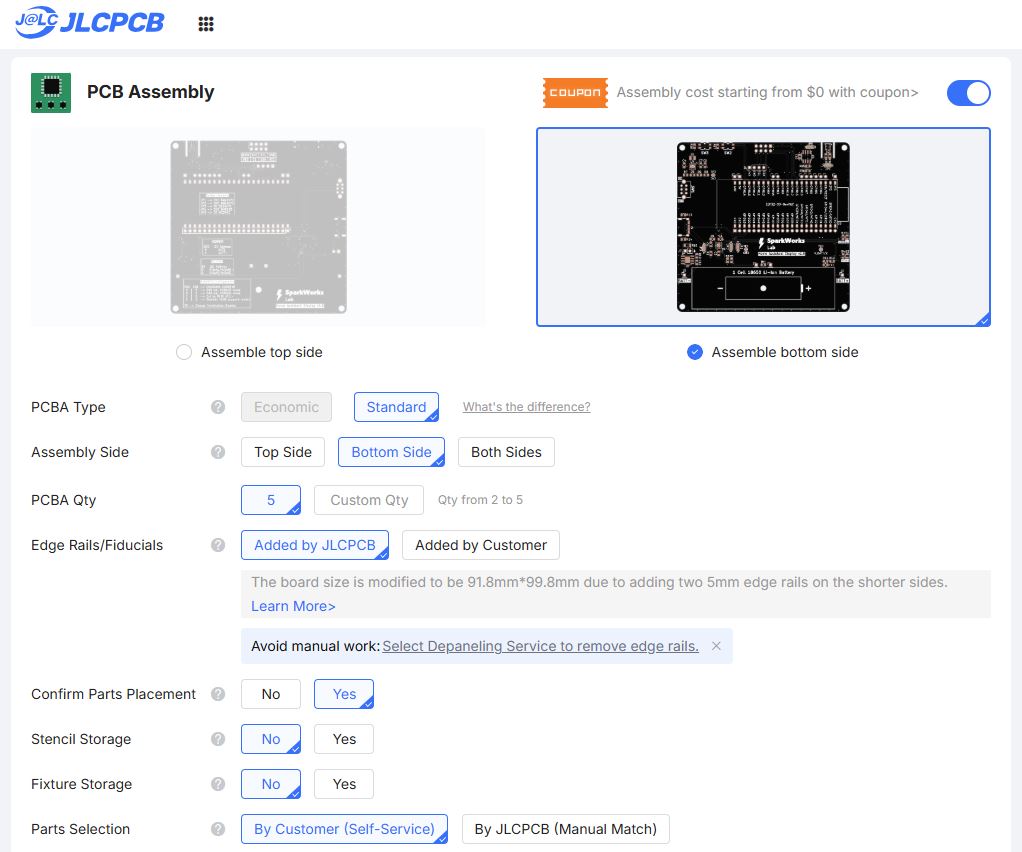
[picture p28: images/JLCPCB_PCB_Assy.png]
JLCPCB PCB Assembly

</div>

10. When **Confirm Parts placement** is activated, you'll be promted whether to Confirm the parts placement automatically after 72h. Mark the checkbox if you don't want parts placement to be confirmed automatically. Ensure you check your e-mail regularly to avoid any delays. 

<div align="center">
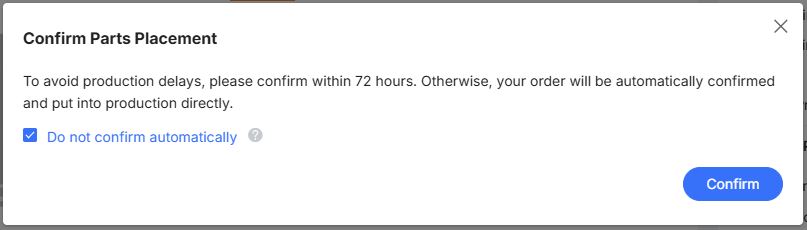
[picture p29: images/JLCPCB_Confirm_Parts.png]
JLCPCB Confirm Parts

</div>

11. Click **Next** in the right side bar. You'll get to the next page where you can see the PCB side it will be assembled. Click **Next** again to get to the next step.

<div align="center">
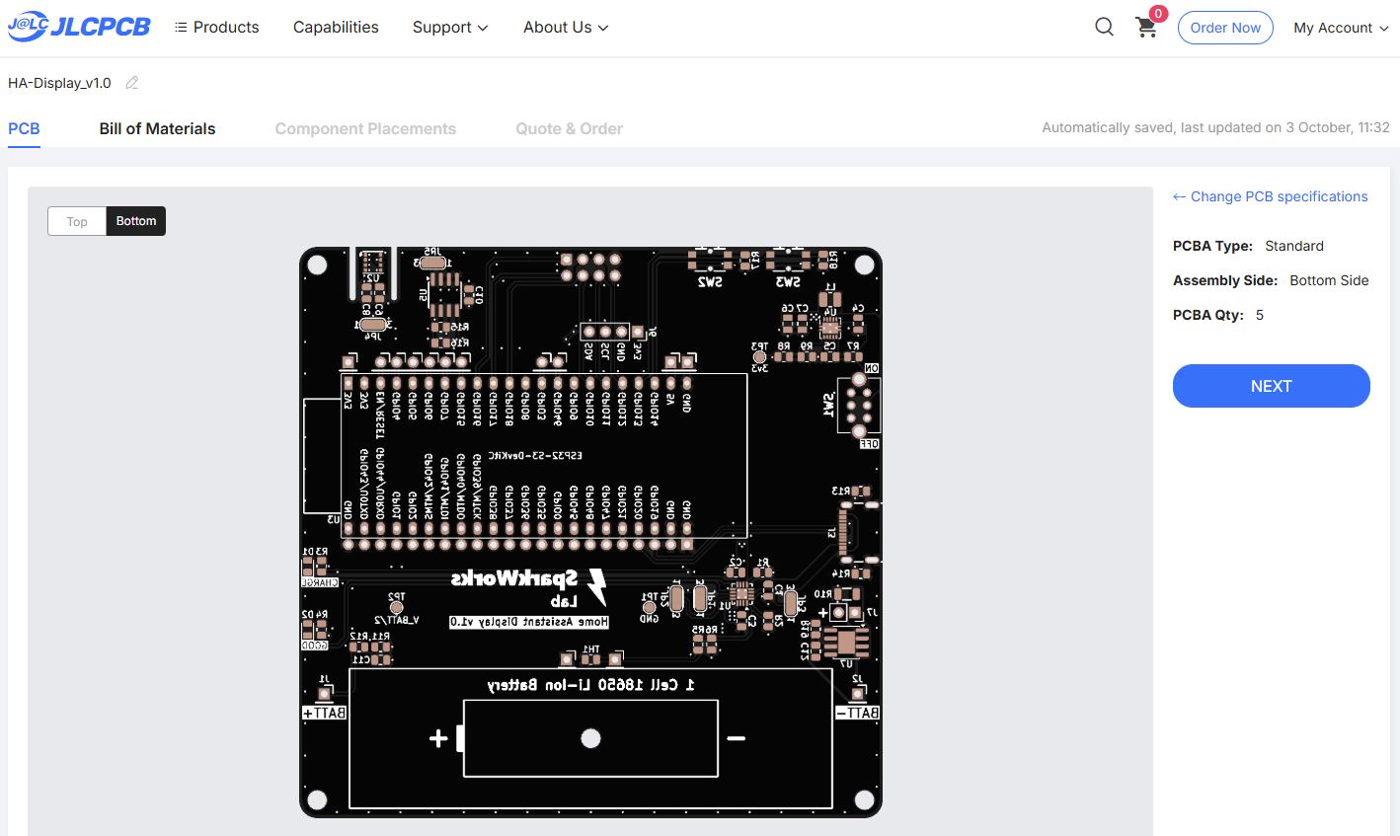
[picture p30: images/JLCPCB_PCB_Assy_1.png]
JLCPCB Assembly

</div>

12. Click **Next** in the right side bar. You'll get to the next page where you must upload the [BOM](HA-Display_v1.0_BOM.csv) and [Centroid file](HA-Display_v1.0-all-pos.csv) files.

<div align="center">
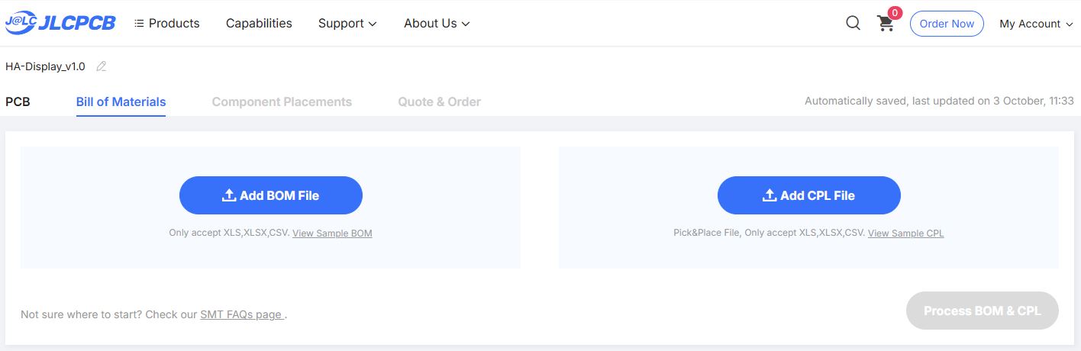
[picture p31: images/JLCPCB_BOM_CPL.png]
JLCPCB BOM CPL

</div>

13. Once BOM and CPL files are correctly uploaded, they will appear in each panel.

<div align="center">
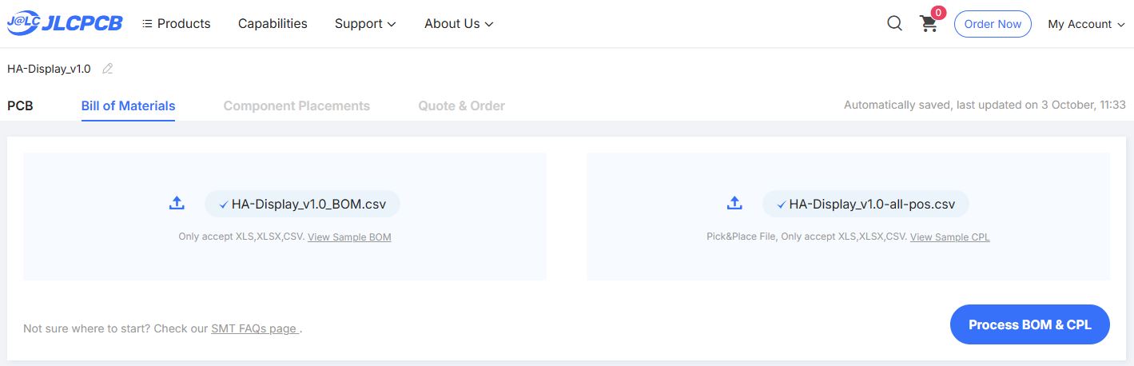
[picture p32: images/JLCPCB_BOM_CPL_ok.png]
JLCPCB BOM CPL OK

</div>

14. Click **Process BOM & CPL** button. It is normal for an error to appear because not all components are included in the assembly. This is expected for this design. Click **Continue** to proceed.

<div align="center">
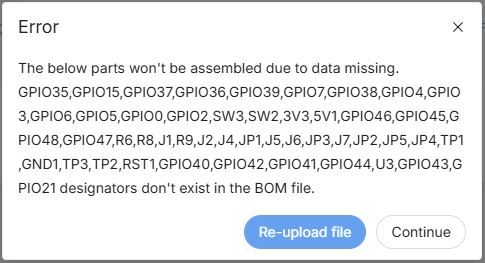
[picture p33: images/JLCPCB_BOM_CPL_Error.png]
JLCPCB BOM CPL Error

</div>

15. Once BOM and CPL files are processed, you will see the **Bill of Materials** with the selected parts. Ensure all of them are checked before moving to the next step. In case some of the parts I sourced are not available, you can look for a replacement part in their [Parts Manager Page](https://jlcpcb.com/user-center/smtPrivateLibrary/). 

<div align="center">
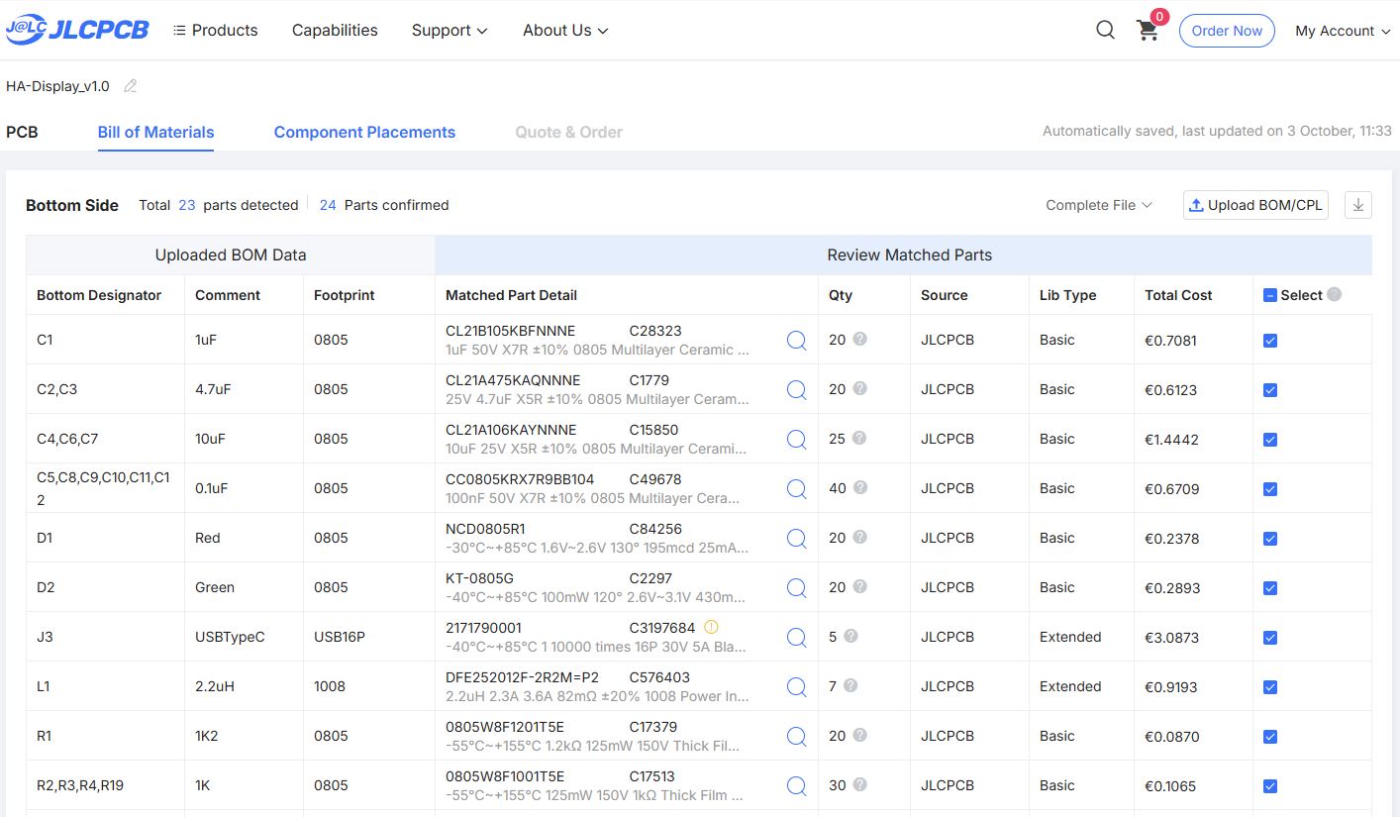
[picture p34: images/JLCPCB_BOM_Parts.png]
JLCPCB BOM Parts

</div>

16. In the next page you see the PCB with the **Components Placement**. Some of them may not be well positioned. You must adapt the position selecting the component to move and rotate or move it to the right placement according to the footprint. 

<div align="center">
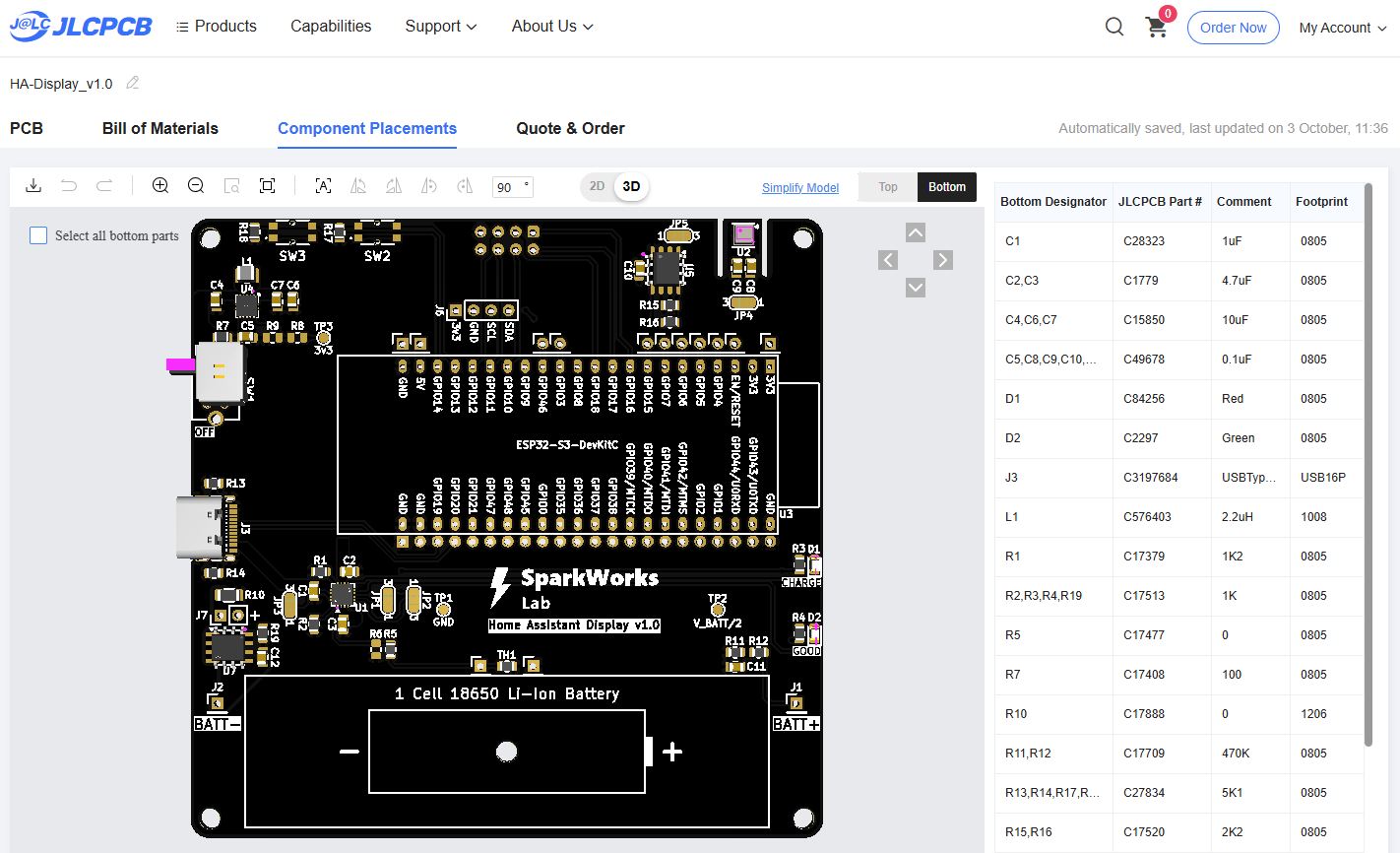
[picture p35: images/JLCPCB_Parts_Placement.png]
JLCPCB Parts Placement

</div>

In my case I've had to relocate:

* Power Switch.
* USB Type-C Connector.

*As these parts are Through Hole, it's easier to ensure proper placement from the Top Side of the PCB.*

<div align="center">
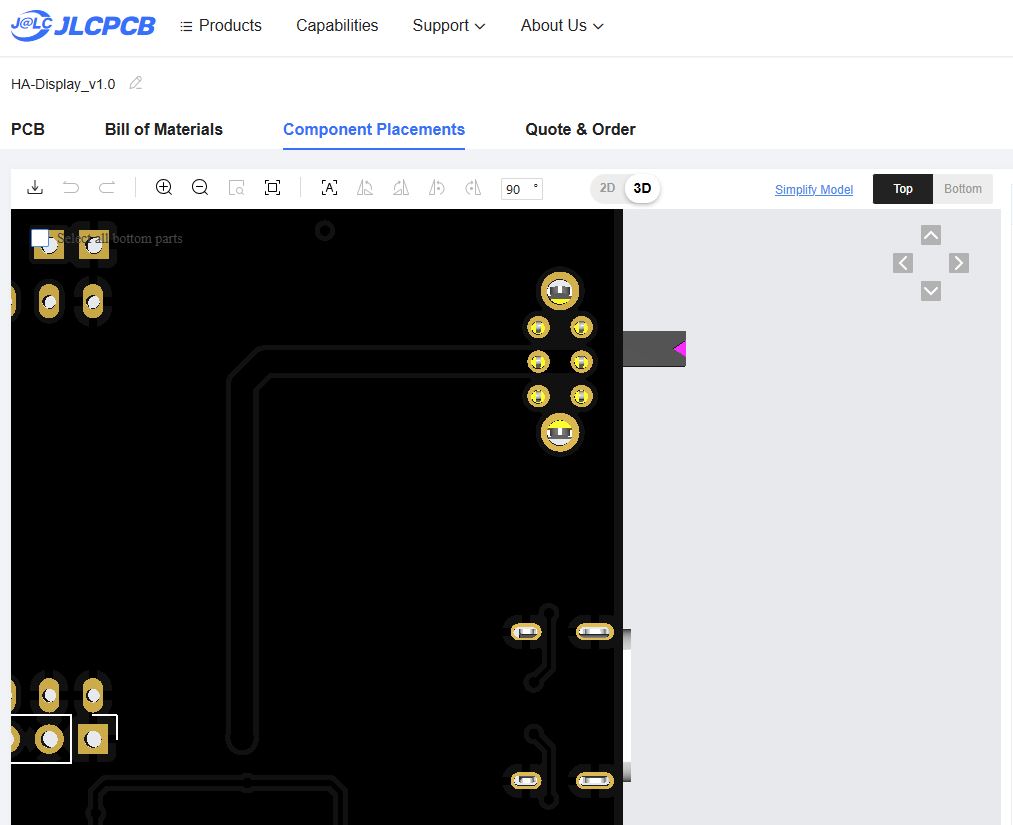
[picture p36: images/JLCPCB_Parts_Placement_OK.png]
JLCPCB Parts Placement 1

</div>

> **Important:** Check the orientation of U2, U5 and U7 before approving the assembly. JLCPCB's placement data may require manual correction.

<div align="center">
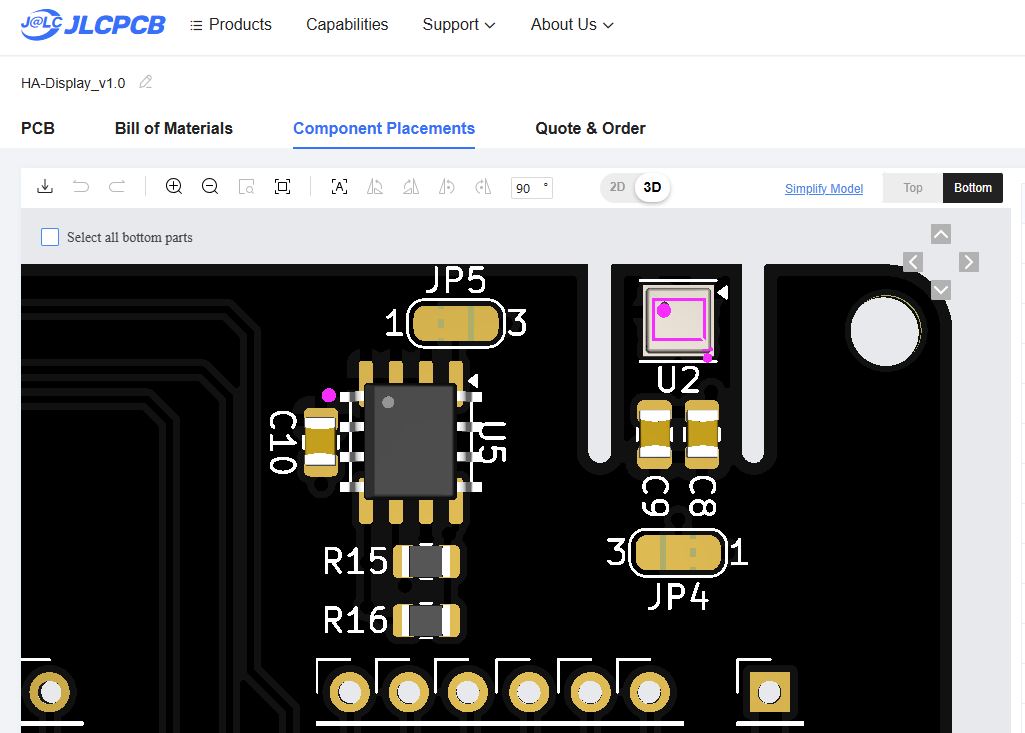
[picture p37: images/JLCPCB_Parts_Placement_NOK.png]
JLCPCB Parts Placement 2

</div>

Ensure the purple dot corresponds to the mark in the footprint (Pin #1).

<div align="center">
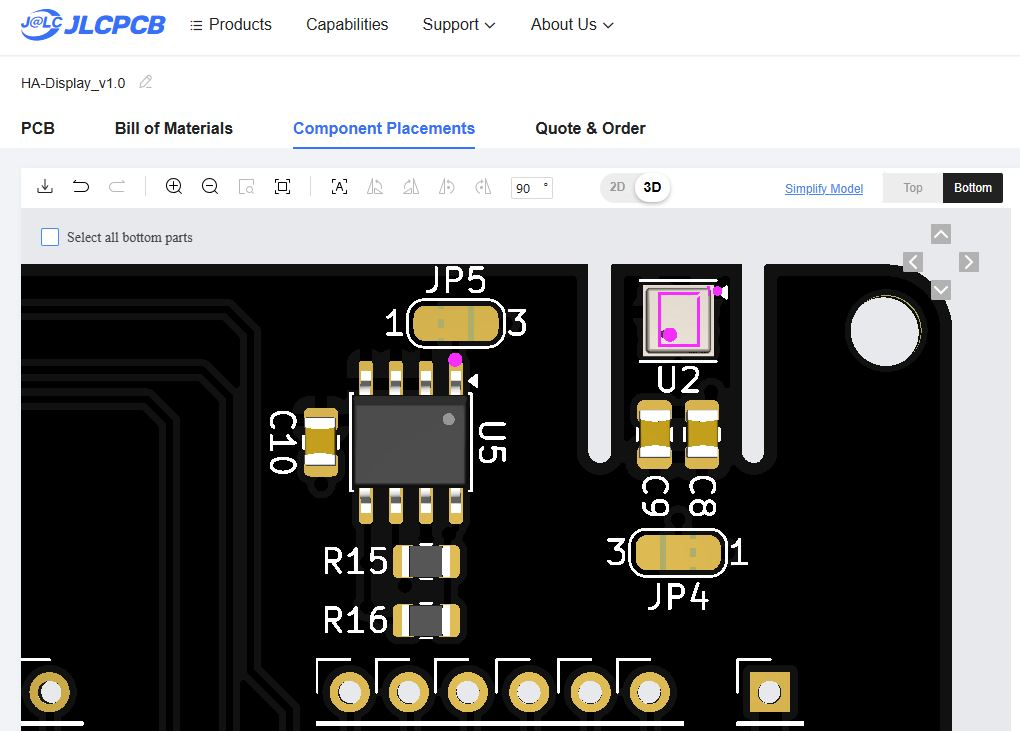
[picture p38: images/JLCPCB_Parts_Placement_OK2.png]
JLCPCB Parts Placement 3

</div>

17. Once you ensured the right placement of all the parts, proceed to the next step **Quote & Order**. You'll see the Quotation of the PCB & Assembly. Select the **Product Description** in the right bar and click **Save to Cart** to move to the Cart page.

<div align="center">
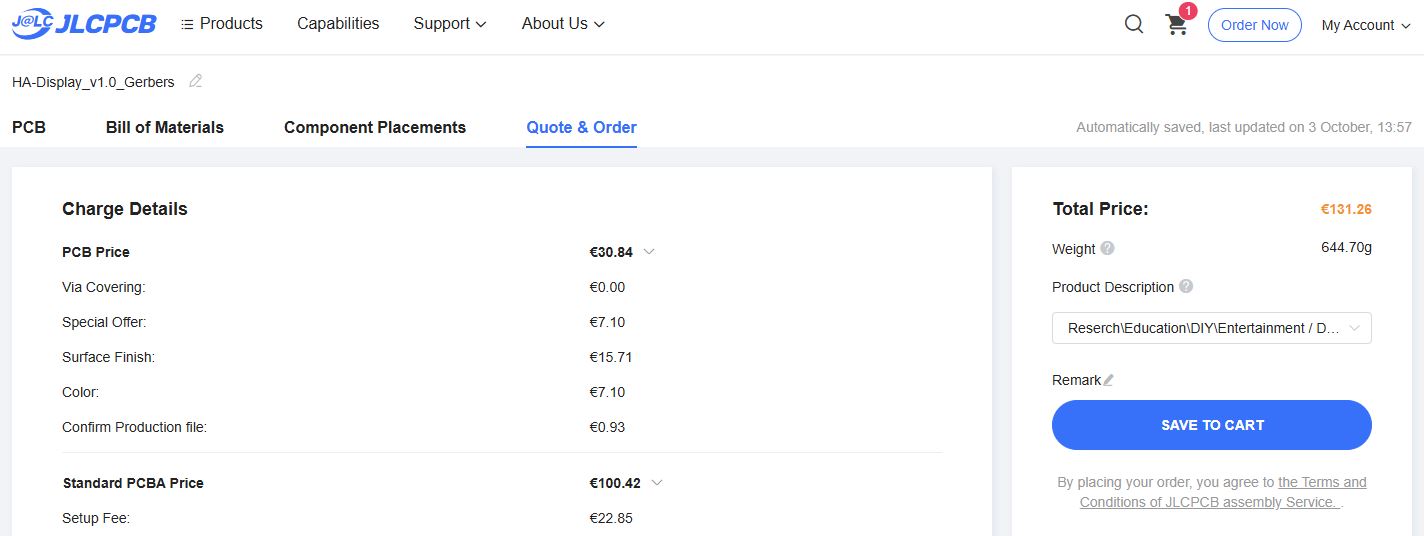
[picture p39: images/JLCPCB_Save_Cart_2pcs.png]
JLCPCB Save Cart

</div>

18. Select the Item to purchase in the **Shopping Cart** page. Shipping method can be selected in the right bar, it can be selected in the next step too.

<div align="center">
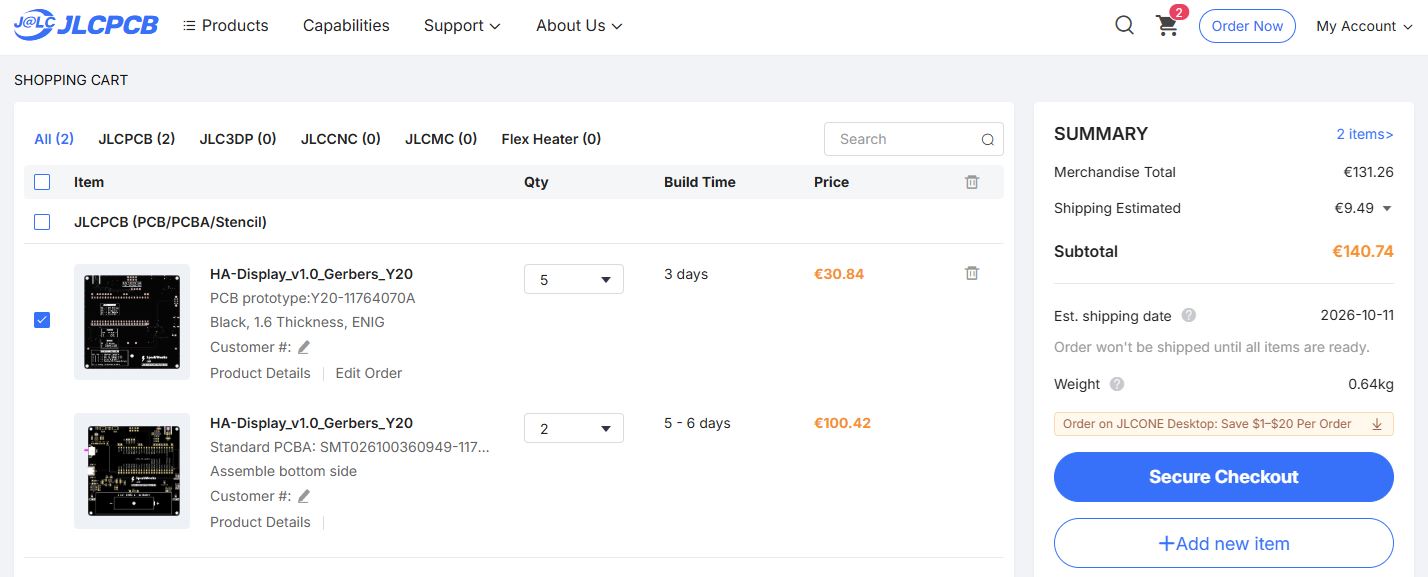
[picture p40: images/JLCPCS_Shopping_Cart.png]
JLCPCB Checkout

</div>

19. I personally use **Global Standard Direct Line** when available, as it has generally provided a convenient shipping option for deliveries to Spain. Shipping options, taxes, duties, and availability may vary depending on the destination and current JLCPCB conditions.

<div align="center">
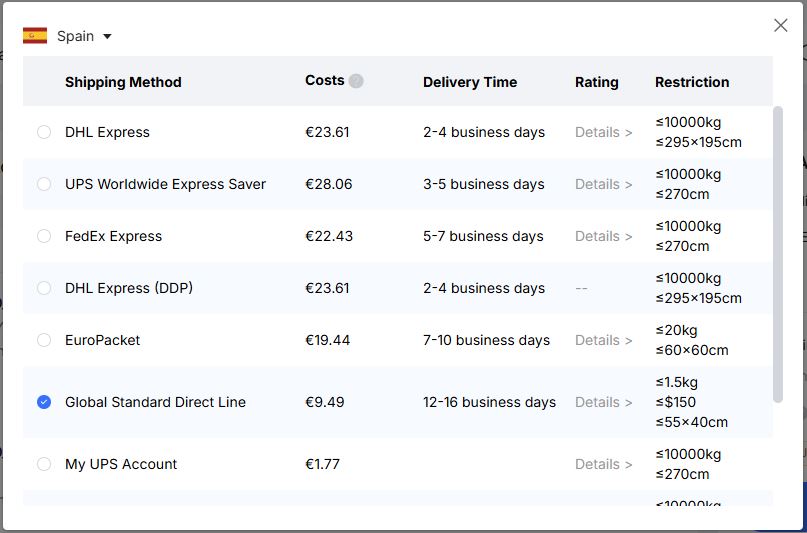
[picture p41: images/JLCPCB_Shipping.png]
JLCPCB Shipping

</div>

20. Select your shipping address and billing information.

<div align="center">
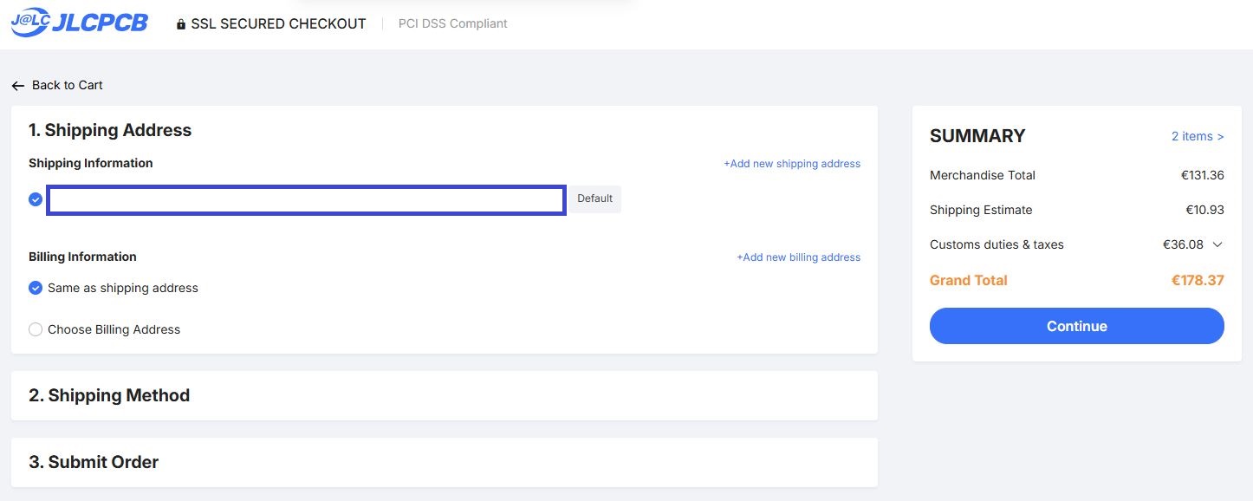
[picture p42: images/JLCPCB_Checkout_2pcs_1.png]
JLCPCB Checkout 1

</div>

21. Select Shipping Method. **Global Standard Direct Line** is recommended.

<div align="center">
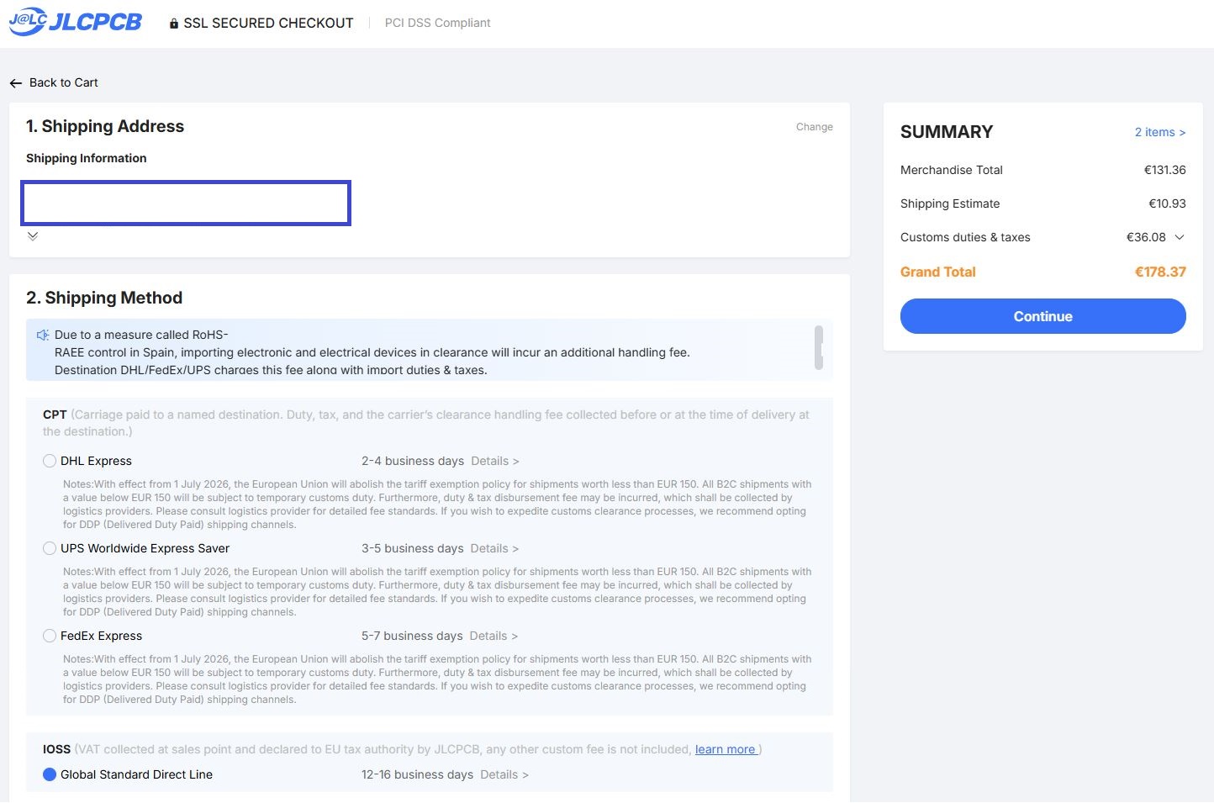
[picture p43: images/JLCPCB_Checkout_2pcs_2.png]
JLCPCB Checkout 2

</div>

22. Select your preferred payment method and click **Submit Order**.

<div align="center">
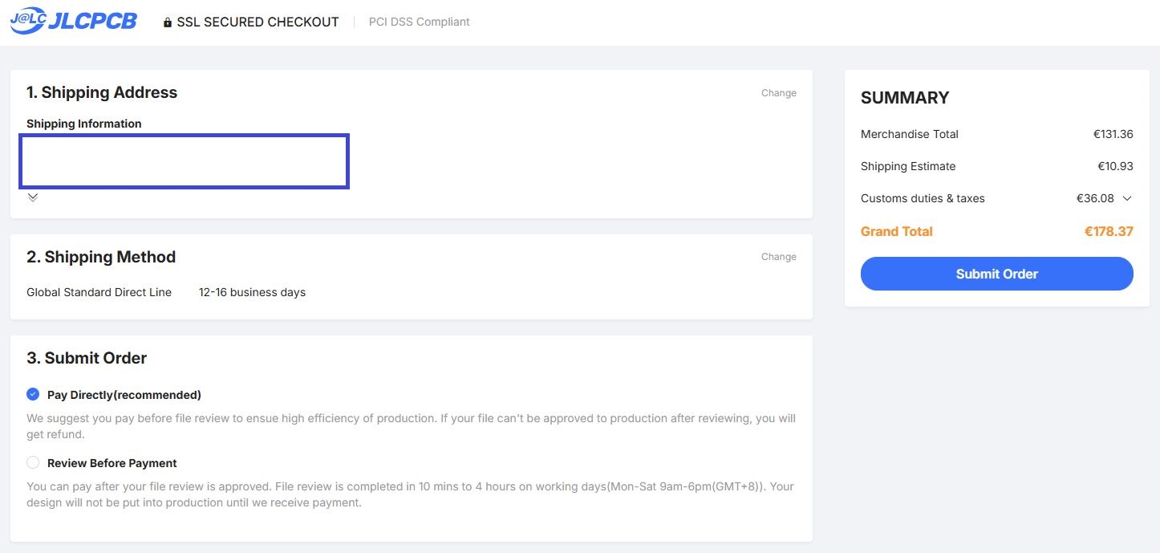
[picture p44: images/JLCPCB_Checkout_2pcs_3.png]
JLCPCB Checkout 3

</div>

23. Once your order is submitted and confirmed, you can track the status in the [Orders](https://jlcpcb.com/user-center/orders/) panel inside your account area.

Be ready to confirm PCB production and Parts Placement in your e-mail in case you checked those options.

> **Note:** The quoted price is provided for reference only. PCB and
> assembly costs can vary significantly depending on the selected
> specifications, quantity, components, and shipping method.
>
> For a lower-cost option, consider **Green soldermask** and
> **Economy PCB Assembly** where available.

## 4. Order the Additional Parts JLCPCB doesn't Assemble

There are a few parts that you will need to order yourself and solder on the PCBs after you receive them from JLCPCB.

Here is a list of the additional parts to order for the PCB:

* 1 × WeAct Studio 4.2" (400 × 300 px) three-color e-paper display.
* 1 × ESP32-S3-DevkitC-1.
* 2 × Momentary pushbuttons. [Würth Electronik 436331045822](https://octopart.com/es/part/wurth-elektronik/436331045822).
* 1 × DPDT Switch in case you used Economy PCB Assembly. [C&K OS202011MA0QN1](https://octopart.com/es/part/c-k-components/OS202011MA0QN1).
* 1 × 18650 Li-Ion Battery Holder & 18650 Cell.
* 2 × Female Headers 2.54mm 22-Pin Single Row for the ESP32-S3-DevkitC-1. *Optional but recommended*.
* 1 × Female Headers 2.54mm 4-Pin Single Row for the I2C expansion port. *Optional but recommended*.

## 5. Finish the PCB

Once you receive the assembled PCB from JLCPCB and the additional parts, install the remaining through-hole and mechanical components:

- ESP32-S3-DevKitC-1 headers.
- Pushbuttons.
- Battery holder.
- I2C expansion headers (optional).
- DPDT switch, if applicable.

After soldering all remaining components, the assembled PCB should look approximately like this:

<div align="center">

HA Display assembled PCB

</div>

## 6. Inspect and Test the Hardware

Before installing the PCB into the enclosure, inspect all solder joints and component orientations.

Pay particular attention to:

- Power input and protection circuitry.
- ESP32-S3-DevKitC-1 orientation.
- BME688/BME680 orientation.
- Pushbutton operation.
- USB-C connector solder joints.
- Power switch orientation.
- Any manually assembled through-hole components.

Check for solder bridges or short circuits before connecting the battery.

## 7. Flash the Firmware to the ESP32-DevkitC-1

Before you attempt to get everything fitted into the enclosure, it's best to make sure all the hardware works.

Install the ESP32-DevkitC-1 into the headers on the PCB.

You'll need to compile the code and flash it into the ESP32-DevkitC-1 on the hardware. Instructions can be found [here](../../../firmware/README.md#installation).

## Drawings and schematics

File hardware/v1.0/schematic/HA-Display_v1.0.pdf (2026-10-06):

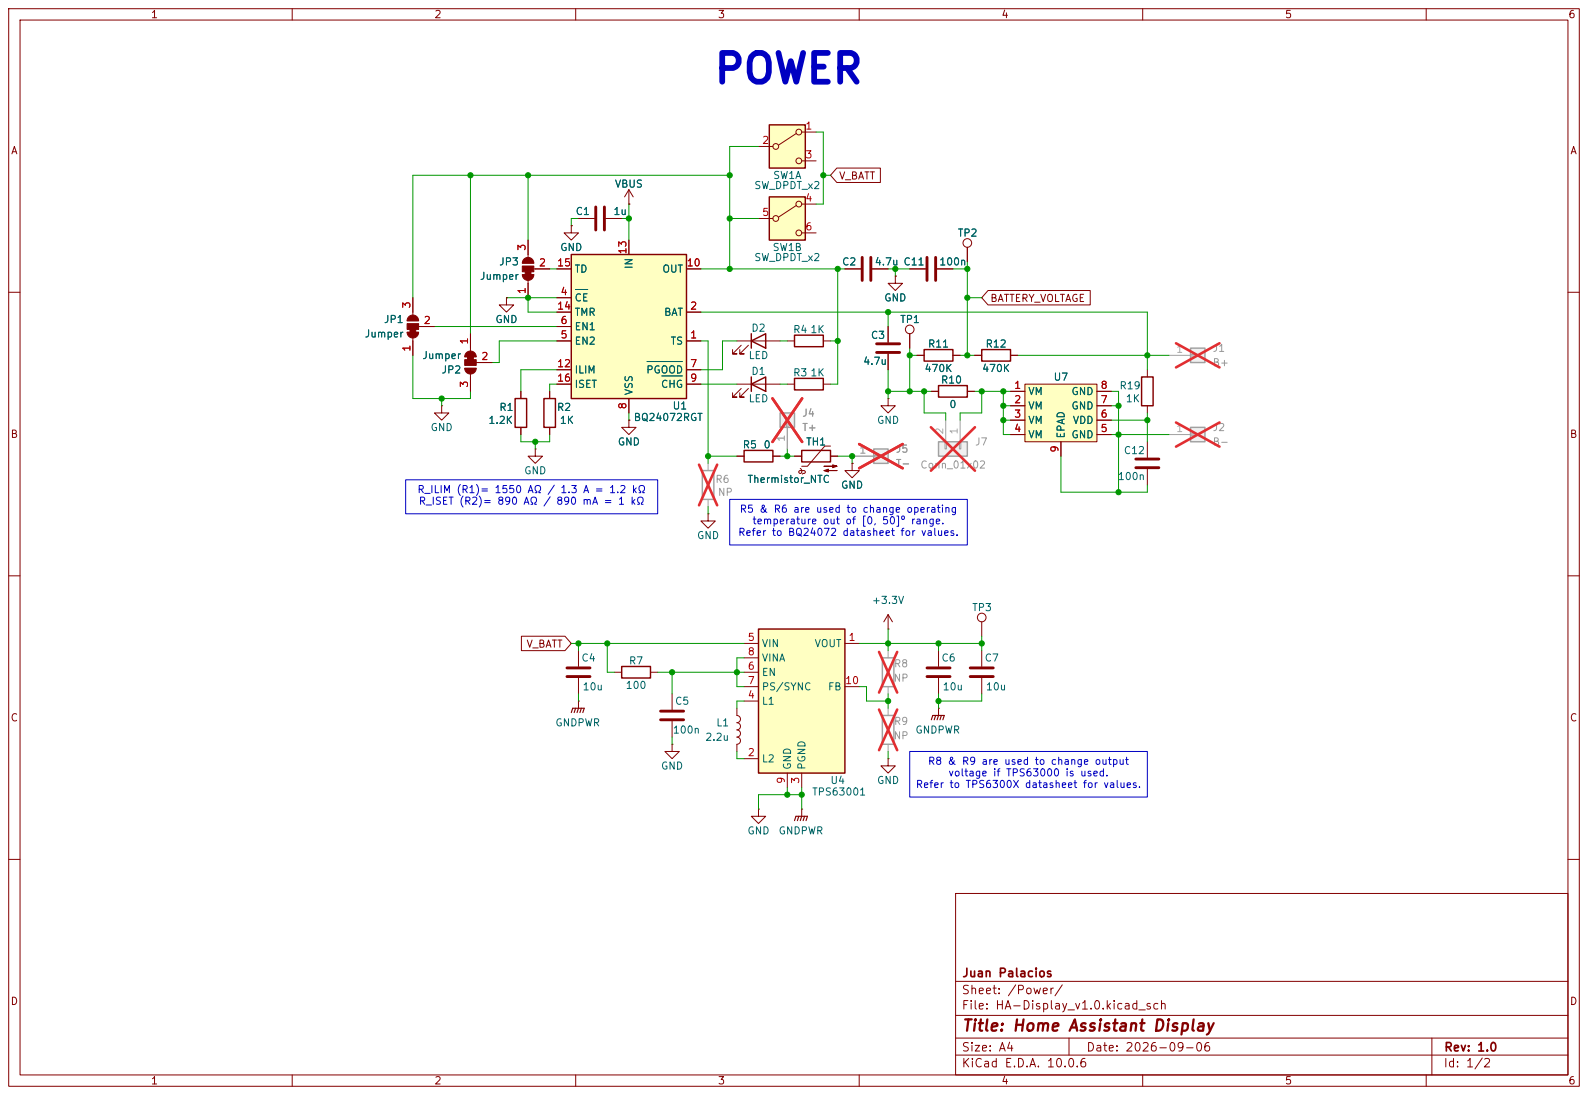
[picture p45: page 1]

voltage if TPS63000 is used. Refer to TPS6300X datasheet for values. R_ILIM (R1)= 1550 AΩ / 1.3 A = 1.2 kΩ

temperature out of [0, 50]º range. Refer to BQ24072 datasheet for values. R8 & R9 are used to change output

Juan Palacios
Sheet: /Power/
File: HA-Display_v1.0.kicad_sch
Title: Home Assistant Display

Size: A4 | Rev: 1.0
KiCad E.D.A. 10.0.6 | Id: 1/2

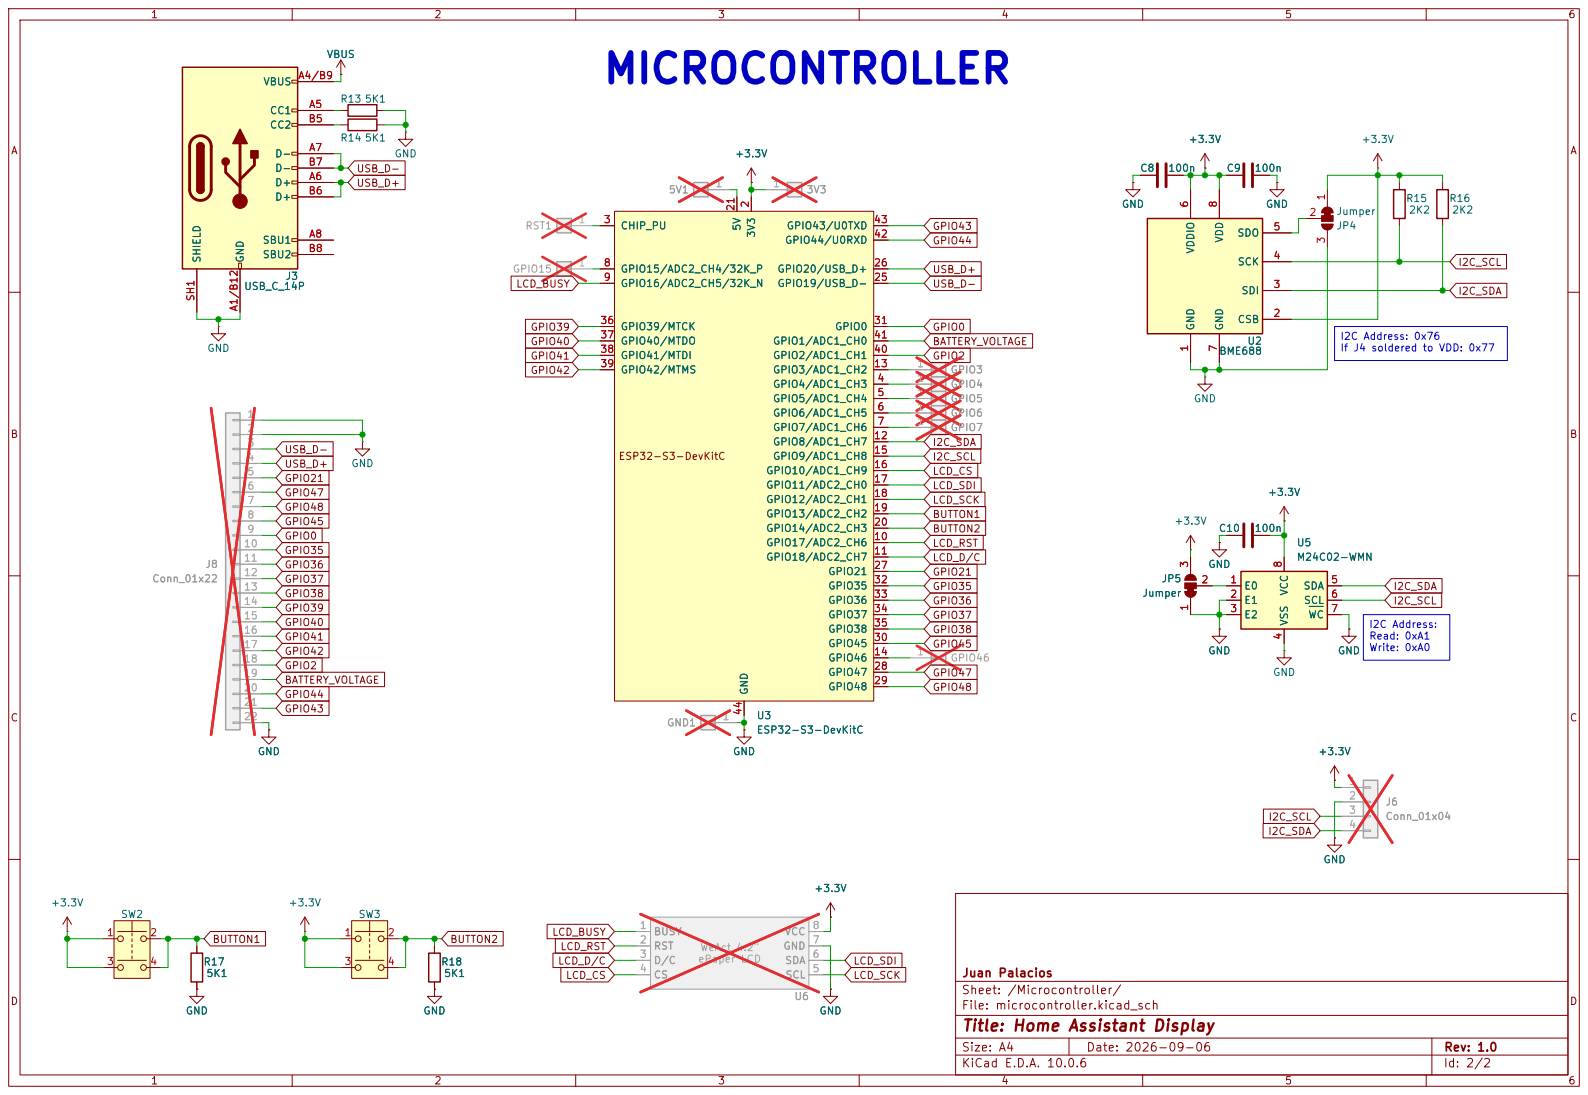
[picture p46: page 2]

If J4 soldered to VDD: 0x77 MICROCONTROLLER

Juan Palacios
Sheet: /Microcontroller/
File: microcontroller.kicad_sch
Title: Home Assistant Display

Size: A4 | Rev: 1.0
KiCad E.D.A. 10.0.6 | Id: 2/2

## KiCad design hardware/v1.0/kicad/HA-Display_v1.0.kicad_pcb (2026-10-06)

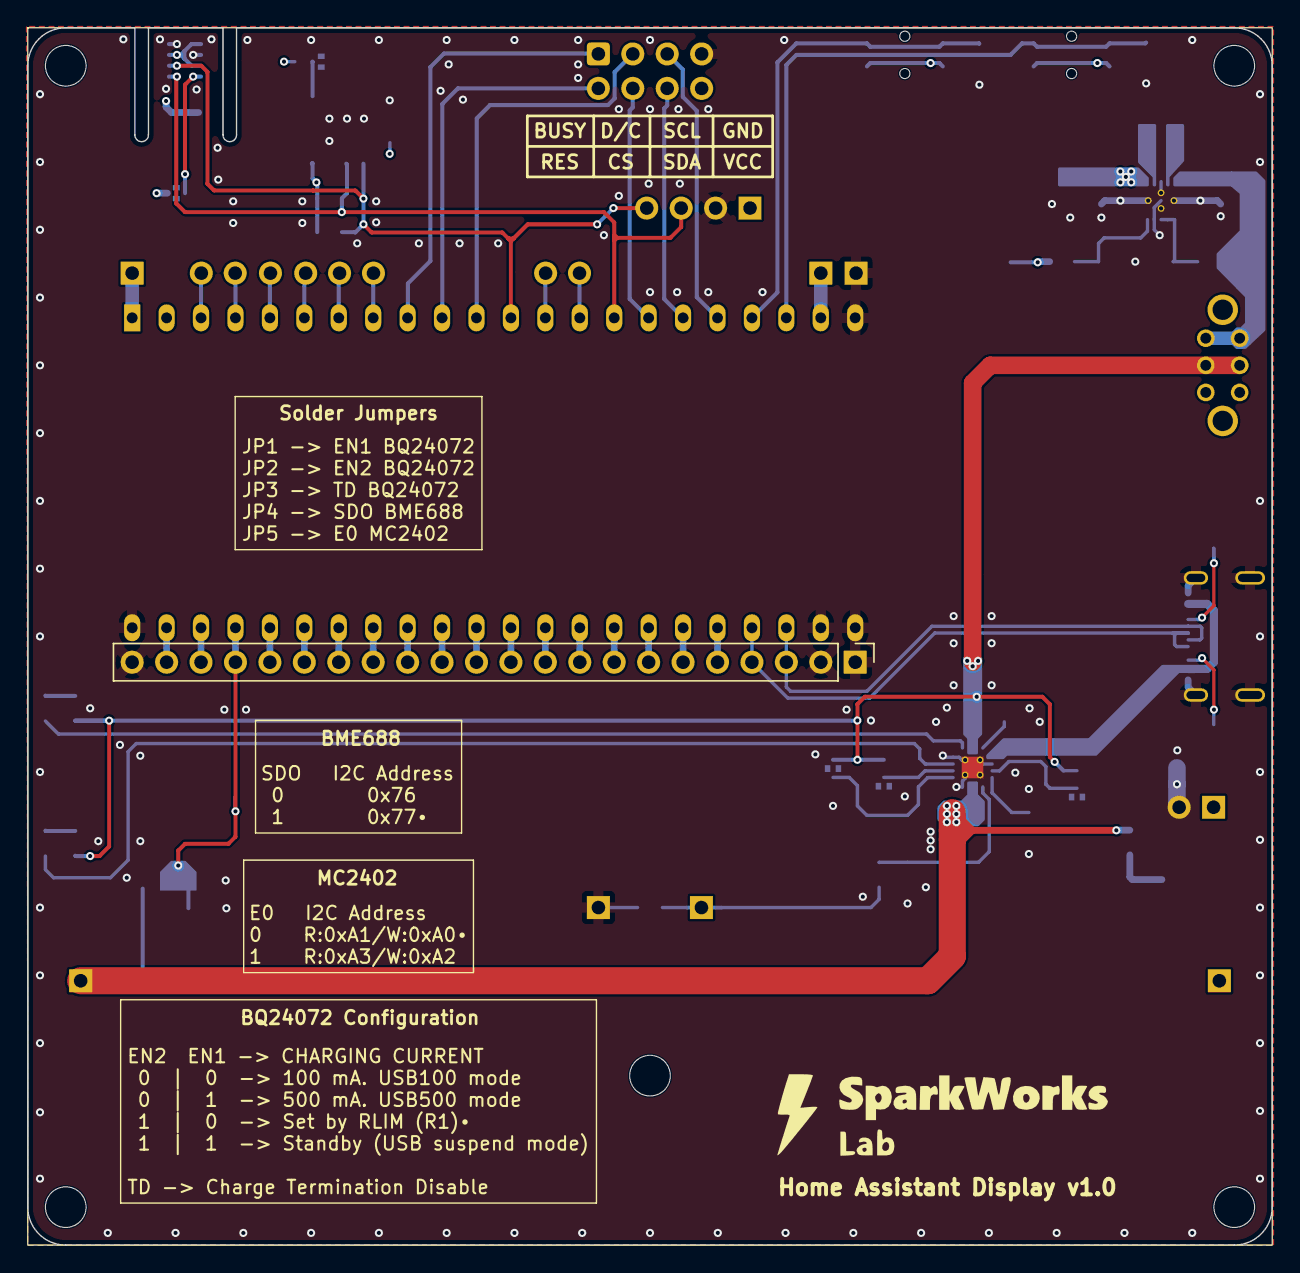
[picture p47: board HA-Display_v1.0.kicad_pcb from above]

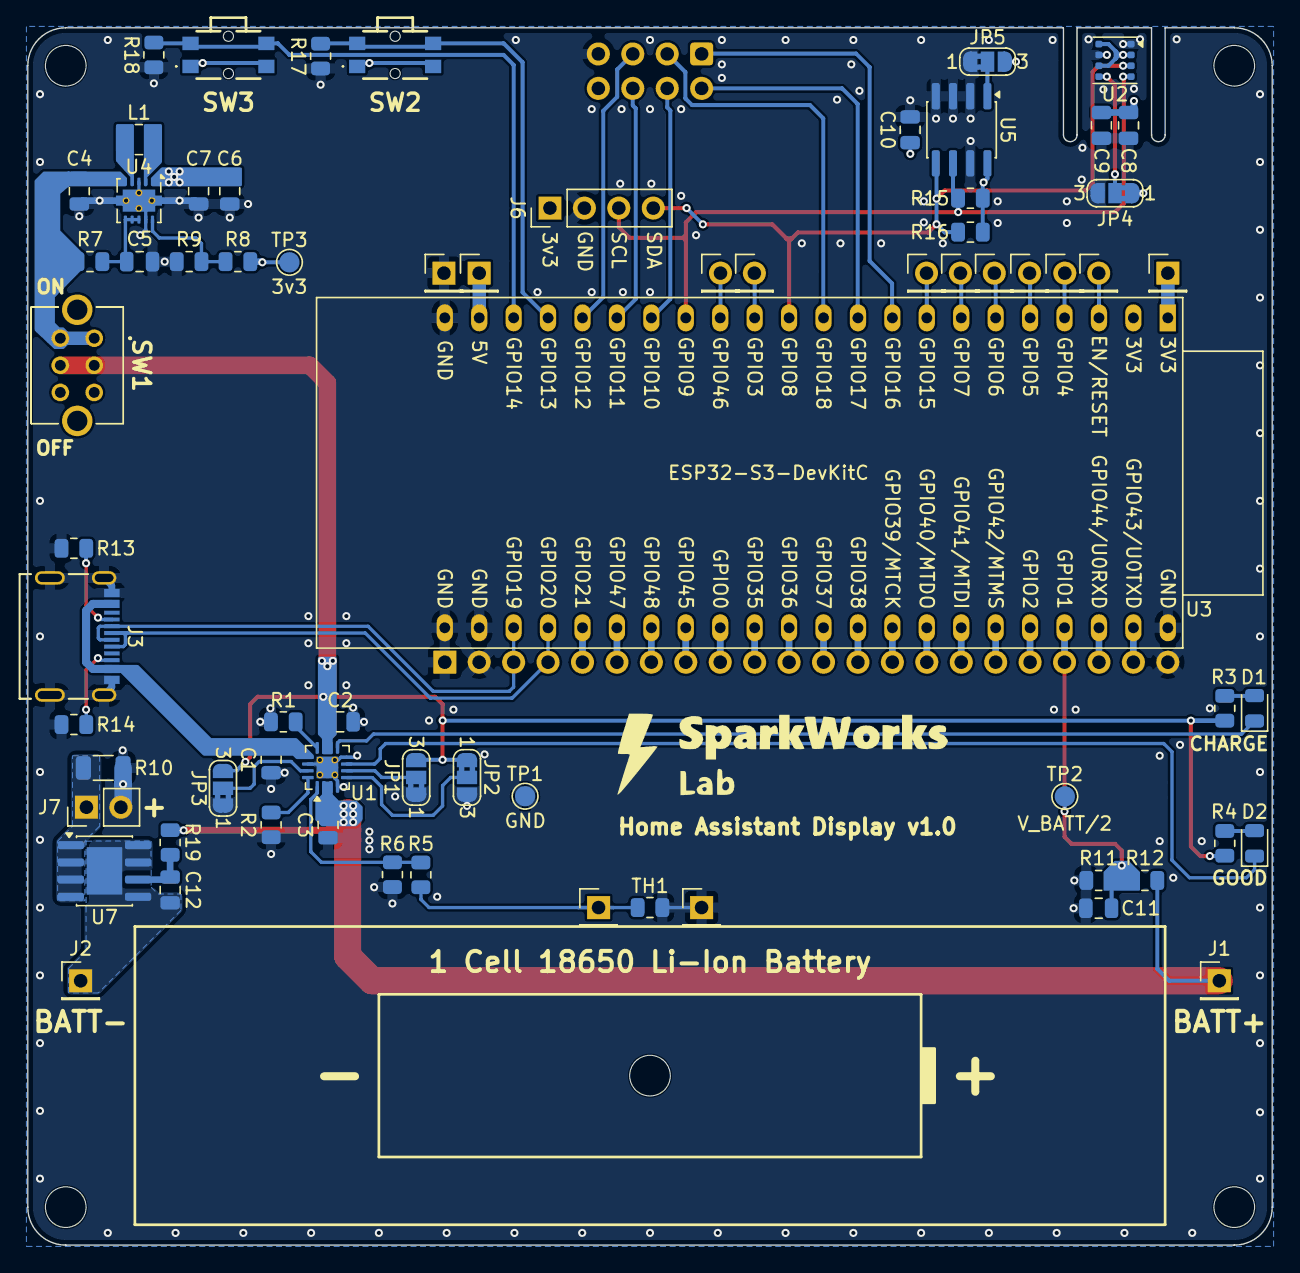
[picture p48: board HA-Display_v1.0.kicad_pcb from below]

Board: 4 copper layers, 91.8 x 89.8 mm, 72 parts (70 on the bottom side), 66 nets.

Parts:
3V3, 5V1: B+; PinHeader_1x01_P2.54mm_Vertical
C1: 1u; C_0805_2012Metric
C2, C3: 4.7u; C_0805_2012Metric
C4, C6, C7: 10u; C_0805_2012Metric
C5, C8, C9, C10, C11, C12: 100n; C_0805_2012Metric
D1, D2: LED; LED_0805_2012Metric
GND1: B+; PinHeader_1x01_P2.54mm_Vertical
GPIO3, GPIO4, GPIO5, GPIO6, GPIO7, GPIO15, GPIO46: B+; PinHeader_1x01_P2.54mm_Vertical
J1: B+; PinHeader_1x01_P2.54mm_Vertical
J2: B-; PinHeader_1x01_P2.54mm_Vertical
J3: USB_C_14P; 2171790001_MOL
J4: T+; PinHeader_1x01_P2.54mm_Vertical
J5: T-; PinHeader_1x01_P2.54mm_Vertical
J6: Conn_01x04; PinHeader_1x04_P2.54mm_Vertical
J7: Conn_01x02; PinHeader_1x02_P2.54mm_Vertical
J8: Conn_01x22; PinHeader_1x22_P2.54mm_Vertical
JP1, JP2, JP3, JP4, JP5: Jumper; SolderJumper-3_P1.3mm_Bridged2Bar12_RoundedPad1.0x1.5mm_Num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
L1: 2.2u; L_1008_2520Metric
R1: 1.2K; R_0805_2012Metric
R2, R3, R4, R19: 1K; R_0805_2012Metric
R5: 0; R_0805_2012Metric
R6, R8, R9: NP; R_0805_2012Metric
R7: 100; R_0805_2012Metric
R10: 0; R_1206_3216Metric
R11, R12: 470K; R_0805_2012Metric
R13, R14, R17, R18: 5K1; R_0805_2012Metric
R15, R16: 2K2; R_0805_2012Metric
RST1: B+; PinHeader_1x01_P2.54mm_Vertical
SW1: SW_DPDT_x2; OS202011MA0QN1
SW2, SW3: SW_Push_Dual; 436331045822
TH1: Thermistor_NTC; R_0805_2012Metric
TP1, TP2, TP3: TestPoint; TestPoint_Pad_D1.5mm
U1: BQ24072RGT; VQFN-16-1EP_3x3mm_P0.5mm_EP1.6x1.6mm_ThermalVias
U2: BME688; Bosch_LGA-8_3x3mm_P0.8mm_ClockwisePinNumbering
U3: ESP32-S3-DevKitC
U4: TPS63001; Texas_DRC0010J_ThermalVias
U5: M24C02-WMN; SOIC-8_3.9x4.9mm_P1.27mm
U6: WeAct_4.2_LCD
U7: SOIC-8-1EP_3.9x4.9mm_P1.27mm_EP2.62x3.51mm

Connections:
+3.3V: 3V3.1 (Pin_1_1), C6.1, C7.1, C8.2, C9.1, C10.2, J6.1, JP4.1 (A), JP5.3 (B), R8.2, R15.2, R16.2, SW2.1, SW2.3, SW3.1, SW3.3, TP3.1 (1_1), U2.2 (CSB), U2.6 (VDDIO), U2.8 (VDD), U3.1 (3V3), U3.2 (3V3), U4.1 (VOUT), U5.8 (VCC), U6.8 (VCC)
BATTERY_VOLTAGE: C11.2, J8.19, R11.2, R12.1, TP2.1 (1_1), U3.41 (GPIO1/ADC1_CH0)
BUTTON1: R17.2, SW2.2, SW2.4, U3.19 (GPIO13/ADC2_CH2)
BUTTON2: R18.2, SW3.2, SW3.4, U3.20 (GPIO14/ADC2_CH3)
GND: C1.2, C2.1, C3.2, C4.2, C5.2, C6.2, C7.2, C8.1, C9.2, C10.1, C11.1, GND1.1 (Pin_1_1), J3.A1/B12 (GND), J3.B1/A12 (GND), J3.SH1 (SHIELD), J3.SH2 (SHIELD), J3.SH3 (SHIELD), J3.SH4 (SHIELD), J5.1 (Pin_1_1), J6.2, J7.2, J8.1, J8.2, J8.22, JP1.1 (A), JP2.3 (B), JP3.1 (A), JP4.3 (B), JP5.1 (A), R1.1, R2.1, R6.1, R9.1, R10.1, R11.1, R13.2, R14.2, R17.1, R18.1, TH1.2, TP1.1 (1_1), U1.4 (~CE), U1.8 (VSS), U1.14 (TMR), U1.17 (VSS), U2.1 (GND), U2.7 (GND), U3.22 (GND), U3.23 (GND), U3.24 (GND), U3.44 (GND), U4.3 (PGND), U4.9 (GND), U4.11 (PGND), U5.2 (E1), U5.3 (E2), U5.4 (VSS), U5.7 (~WC), U6.7 (GND)
GPIO0: J8.9, U3.31 (GPIO0)
GPIO2: J8.18, U3.40 (GPIO2/ADC1_CH1)
GPIO21: J8.5, U3.27 (GPIO21)
GPIO35: J8.10, U3.32 (GPIO35)
GPIO36: J8.11, U3.33 (GPIO36)
GPIO37: J8.12, U3.34 (GPIO37)
GPIO38: J8.13, U3.35 (GPIO38)
GPIO39: J8.14, U3.36 (GPIO39/MTCK)
GPIO40: J8.15, U3.37 (GPIO40/MTDO)
GPIO41: J8.16, U3.38 (GPIO41/MTDI)
GPIO42: J8.17, U3.39 (GPIO42/MTMS)
GPIO43: J8.21, U3.43 (GPIO43/U0TXD)
GPIO44: J8.20, U3.42 (GPIO44/U0RXD)
GPIO45: J8.8, U3.30 (GPIO45)
GPIO47: J8.6, U3.28 (GPIO47)
GPIO48: J8.7, U3.29 (GPIO48)
I2C_SCL: J6.3, R15.1, U2.4 (SCK), U3.15 (GPIO9/ADC1_CH8), U5.6 (SCL)
I2C_SDA: J6.4, R16.1, U2.3 (SDI), U3.12 (GPIO8/ADC1_CH7), U5.5 (SDA)
LCD_BUSY: U3.9 (GPIO16/ADC2_CH5/32K_N), U6.1 (BUSY)
LCD_CS: U3.16 (GPIO10/ADC1_CH9), U6.4 (CS)
LCD_D/C: U3.11 (GPIO18/ADC2_CH7), U6.3 (D/C)
LCD_RST: U3.10 (GPIO17/ADC2_CH6), U6.2 (RST)
LCD_SCK: U3.18 (GPIO12/ADC2_CH1), U6.5 (SCL)
LCD_SDI: U3.17 (GPIO11/ADC2_CH0), U6.6 (SDA)
unnamed: 5V1.1 (Pin_1_1), U3.21 (5V)
unnamed: D1.2 (A), R3.1
unnamed: D1.1 (K), U1.9 (~CHG)
unnamed: D2.2 (A), R4.1
unnamed: D2.1 (K), U1.7 (~PGOOD)
unnamed: GPIO3.1 (Pin_1_1), U3.13 (GPIO3/ADC1_CH2)
unnamed: GPIO4.1 (Pin_1_1), U3.4 (GPIO4/ADC1_CH3)
unnamed: GPIO5.1 (Pin_1_1), U3.5 (GPIO5/ADC1_CH4)
unnamed: GPIO6.1 (Pin_1_1), U3.6 (GPIO6/ADC1_CH5)
unnamed: GPIO7.1 (Pin_1_1), U3.7 (GPIO7/ADC1_CH6)
unnamed: GPIO15.1 (Pin_1_1), U3.8 (GPIO15/ADC2_CH4/32K_P)
unnamed: GPIO46.1 (Pin_1_1), U3.14 (GPIO46)
unnamed: C3.1, J1.1 (Pin_1_1), R12.2, R19.2, U1.2 (BAT), U1.3 (BAT)
unnamed: C12.2, J2.1 (Pin_1_1), U7.5 (GND), U7.7 (GND), U7.8 (GND), U7.9 (EPAD)
unnamed: J3.A5 (CC1), R13.1
unnamed: J3.B5 (CC2), R14.1
unnamed: J4.1 (Pin_1_1), R5.2, TH1.1
unnamed: J7.1, R10.2, U7.1 (VM), U7.2 (VM), U7.3 (VM), U7.4 (VM)
unnamed: C2.2, JP1.3 (B), JP2.1 (A), JP3.3 (B), R3.2, R4.2, SW1.2 (B), SW1.5 (B), U1.10 (OUT), U1.11 (OUT)
unnamed: JP1.2 (C), U1.6 (EN1)
unnamed: JP2.2 (C), U1.5 (EN2)
unnamed: JP3.2 (C), U1.15 (TD)
unnamed: JP4.2 (C), U2.5 (SDO)
unnamed: JP5.2 (C), U5.1 (E0)
unnamed: RST1.1 (Pin_1_1), U3.3 (CHIP_PU)
unnamed: R1.2, U1.12 (ILIM)
unnamed: R2.2, U1.16 (ISET)
unnamed: R5.1, R6.2, U1.1 (TS)
unnamed: C5.1, R7.2, U4.6 (EN), U4.7 (PS/SYNC), U4.8 (VINA)
unnamed: R8.1, R9.2, U4.10 (FB)
unnamed: L1.2, U4.4 (L1)
unnamed: L1.1, U4.2 (L2)
unnamed: C12.1, R19.1, U7.6 (VDD)
USB_D+: J3.A6 (D+), J3.B6 (D+), J8.4, U3.26 (GPIO20/USB_D+)
USB_D-: J3.A7 (D-), J3.B7 (D-), J8.3, U3.25 (GPIO19/USB_D-)
VBUS: C1.1, J3.A4/B9 (VBUS), J3.B4/A9 (VBUS), U1.13 (IN)
V_BATT: C4.1, R7.1, SW1.1 (A), SW1.4 (A), U4.5 (VIN)

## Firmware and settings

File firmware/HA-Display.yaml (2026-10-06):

# =============================================================================
# Home Assistant Display
# =============================================================================
#
# Main ESPHome configuration file.
#
# Includes the project packages, external header files, and hardware-specific
# configuration required to build the Home Assistant Display firmware.

esphome:
  name: ha-display
  includes:
    - include/led.h
    - include/layout.h
    - include/weather_icons.h
    - include/battery.h
    - include/display.h                             # Comment this line to use BSEC2.
    #- include/display_bsec.h                       # Uncomment this line to use BSEC2.
    - include/power.h
  on_boot:
    priority: -100
    then:
      # Refresh Screen
      - script.execute: refresh_display          

# ESP32 DevKit definition.
esp32:
  board: esp32-s3-devkitc-1
  framework:
    type: esp-idf

# YAML files includes.
packages:
  wifi: !include packages/wifi.yaml
  entities: !include packages/entities.yaml
  sensor: !include packages/sensors.yaml            # Comment this line to use BSEC2.
  #sensor: !include packages/sensors_bsec.yaml      # Uncomment this line to use BSEC2.
  font: !include packages/fonts.yaml
  display: !include packages/display.yaml
  forecast: !include packages/forecast.yaml

api:
  reboot_timeout: 0s

# UART Log, change the level if debugging informaiton is needed.
logger:
  level: NONE
  #level: VERY_VERBOSE
  hardware_uart: UART0

# Deep Sleep.
deep_sleep:
  id: deep_sleep_control
  #run_duration: 75s
  sleep_duration: 15min
  
  esp32_ext1_wakeup:
    pins:
      - number: GPIO4       # Prototype PCB.
      #- number: GPIO13     # v1.0 Hardware.
    mode: ANY_HIGH

# Time entity. 
time:
  - platform: homeassistant
    id: ha_time

# Debug LED.
light:
  - platform: esp32_rmt_led_strip
    id: status_led

    pin: GPIO48

    chipset: WS2812
    rgb_order: GRB

    num_leds: 1

    default_transition_length: 0s
    restore_mode: ALWAYS_OFF

# BME68x I2C bus.
i2c:
  sda: GPIO8
  scl: GPIO9
  frequency: 400kHz
  scan: true
  id: i2c_a

# Display SPI.
spi:
  clk_pin: GPIO12
  mosi_pin: GPIO11 

# Global variables.
globals:
  - id: wifi_ok
    type: bool
    restore_value: no
    initial_value: 'false'

  - id: ha_ok
    type: bool
    restore_value: no
    initial_value: 'false'

  - id: sleep_time
    type: int 
    restore_value: no
    initial_value: '0'

  - id: display_update_counter
    type: int
    restore_value: no
    initial_value: '0'

# Timer to update screen when Deep Sleep is OFF.
interval:
  - interval: 1min
    then:
      - if:
          condition:
            binary_sensor.is_off: ha_display_deep_sleep
          then:
            # Increase counter.
            - lambda: |-
                id(display_update_counter)++;

            - if:
                condition:
                  # Check counter and sleep duration.
                  lambda: |-
                    const float sleep_duration = id(ha_sleep_duration).state;
                    return !isnan(sleep_duration) &&
                           sleep_duration > 0 &&
                           id(display_update_counter) >= (int) sleep_duration;
                then:
                  # Update screen if the configured interval has elapsed.
                  - lambda: |-
                      id(display_update_counter) = 0;
                  - script.execute: refresh_display
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

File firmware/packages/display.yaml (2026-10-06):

# =============================================================================
# Display Configuration
# =============================================================================
#
# Configures the e-paper display and the main display update lambda.
#
# The display layout is implemented through reusable drawing functions defined
# in the project header files.

display:
  - platform: epaper_spi
    id: eink
    model: WeAct-4.2in-3c
    dimensions:
      width: 400
      height: 300
    cs_pin: GPIO10            
    busy_pin: GPIO18          # Prototype PCB.
    dc_pin: GPIO17            # Prototype PCB.
    reset_pin: GPIO16         # Prototype PCB.
    #busy_pin: GPIO16         # v1.0 Hardware.
    #dc_pin: GPIO18           # v1.0 Hardware.
    #reset_pin: GPIO17        # v1.0 Hardware.

    reset_duration: 2ms
    update_interval: never
    full_update_every: 1
    data_rate: 10MHz

    lambda: |-

      drawFrame(it);

      drawHeader(it);

      drawForecast(it);

      drawAirSensor(it);

      drawSmartPlugs(it);

      drawRoomSensors(it);
      
